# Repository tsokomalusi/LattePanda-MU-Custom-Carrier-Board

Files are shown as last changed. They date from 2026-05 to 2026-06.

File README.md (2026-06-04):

# LattePanda MU Custom Carrier Board

## High Speed PCB Design in KiCad

This repository contains a high-speed PCB design practice project created in KiCad
as part of the High Speed Design with KiCad course by D. Peter Dalmaris.

The primary goal of this project was to gain practical experience with modern
high-speed PCB layout techniques, signal integrity awareness, PCB stackup planning,
and manufacturability considerations.

# Project Background

The project workflow was inspired by the DFRobot LattePanda MU Carrier Board.

As part of the learning process:

- Existing PCB design constraints were studied
- PCB stackup parameters were imported into KiCad
- Routing practices from the reference design were analyzed
- High-speed layout techniques were explored through practical implementation
- Differential pair routing and length tuning techniques were practiced
- Teardrops were implemented throughout the PCB design process

PCIe functionality was not implemented, as the primary focus of the project
was PCB layout practice, signal routing exposure, and understanding high-speed
design workflows.

# 3D PCB Views

## Top Side
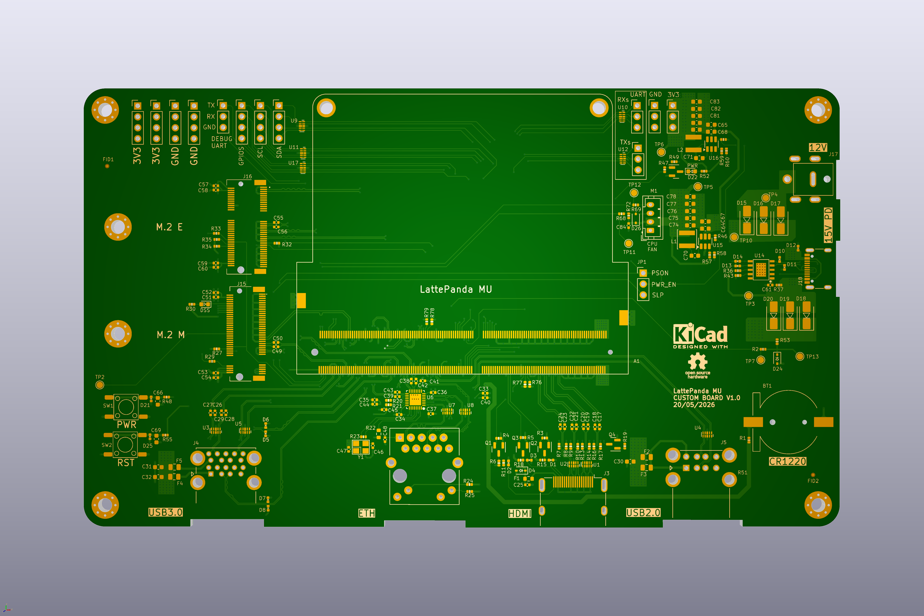
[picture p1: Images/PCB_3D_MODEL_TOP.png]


## Bottom Side
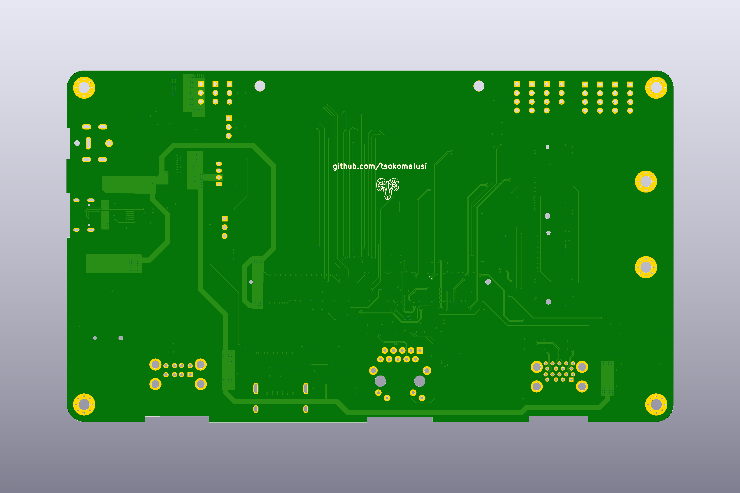
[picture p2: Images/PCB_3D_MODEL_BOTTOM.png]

## Overview

# Technologies & Concepts

 USB 3.0 high-speed routing
- HDMI interface routing
- Gigabit Ethernet routing
- M.2 connector integration
- Differential pair routing and length tuning
- Controlled impedance awareness
- PCB stackup planning
- Return path considerations
- Teardrop implementation
- DFM analysis using NextPCB HQDFM tools

## Design Goals

The project focused on learning and applying:

- High-speed routing practices
- Differential pair management
- Signal integrity fundamentals
- PCB stackup awareness
- Manufacturability considerations

# PCB Stackup & Impedance Planning

The PCB stackup and impedance calculations were reviewed using the NextPCB
impedance calculator and stackup tools.

## Impedance Calculator

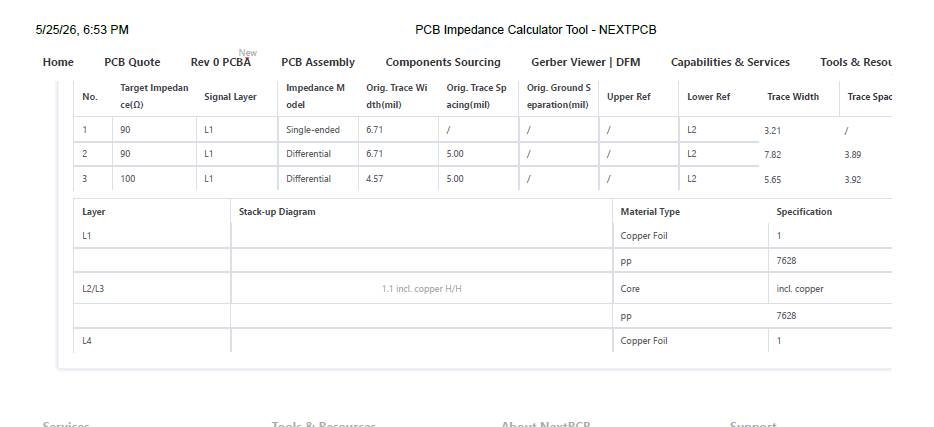
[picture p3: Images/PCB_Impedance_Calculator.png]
IMPEDANCE_CAL


## NextPCB Stackup : Huaqiu04161H03-7628

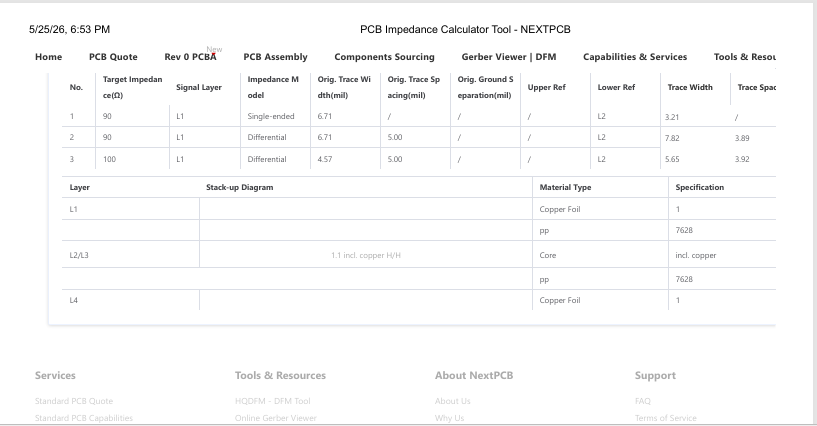
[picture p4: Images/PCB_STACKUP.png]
PCB_STACKUP


## KiCad Stackup Configuration

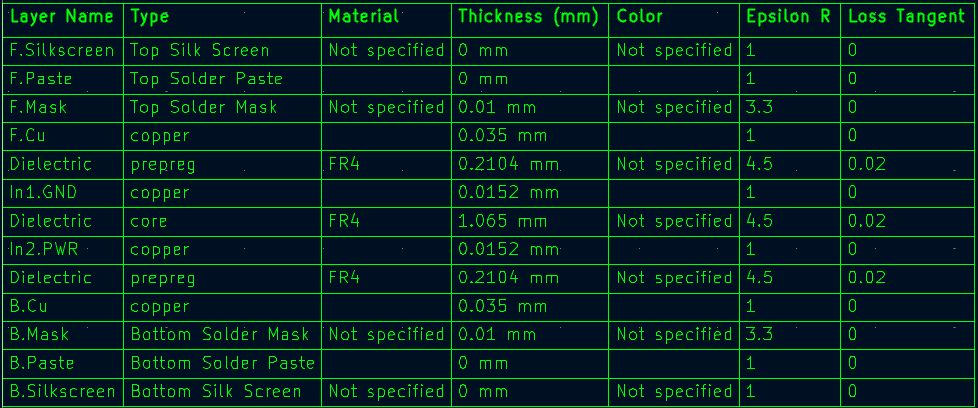
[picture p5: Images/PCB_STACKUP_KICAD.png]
PCB_STACKUP


## PCB Layout

### Full PCB Overview

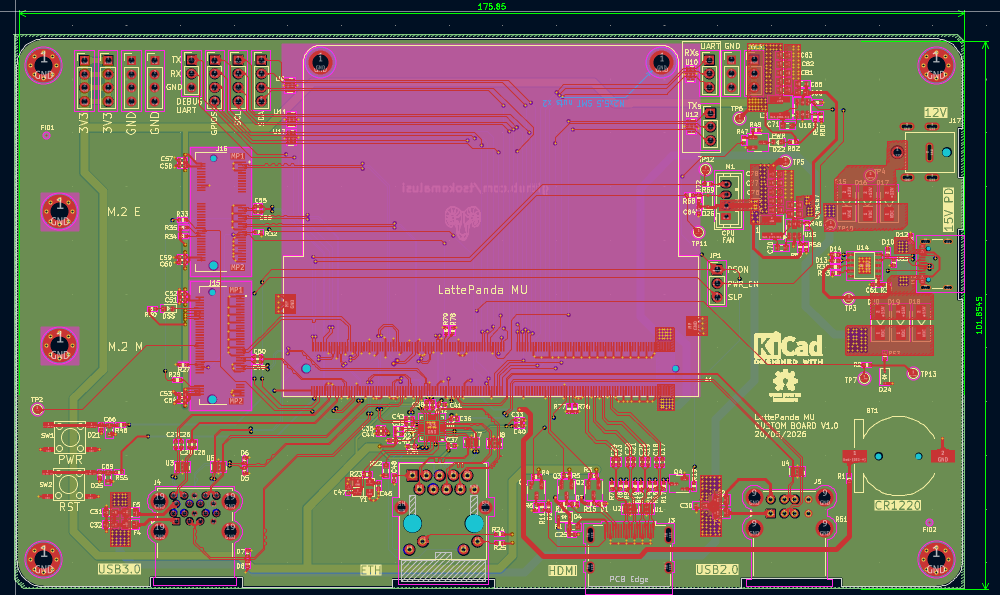
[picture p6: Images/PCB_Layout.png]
PCB Layout


# High-Speed Routing Examples

### USB 3.0 Routing

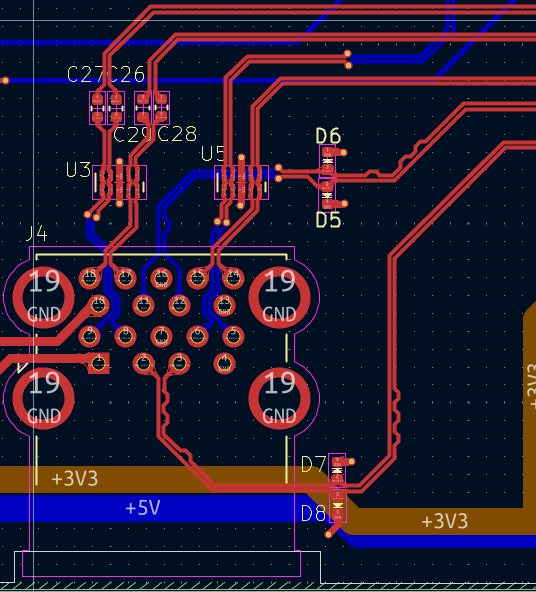
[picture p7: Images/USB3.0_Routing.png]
USB3 Routing


### Notes

- Differential pair routing applied to SuperSpeed signals
- Length tuning performed using KiCad tuning tools
- Pair spacing kept as consistent as possible
- Via transitions minimized where practical
- Teardrops applied throughout the routing process
- ESD protection placed close to connectors

### HDMI Routing

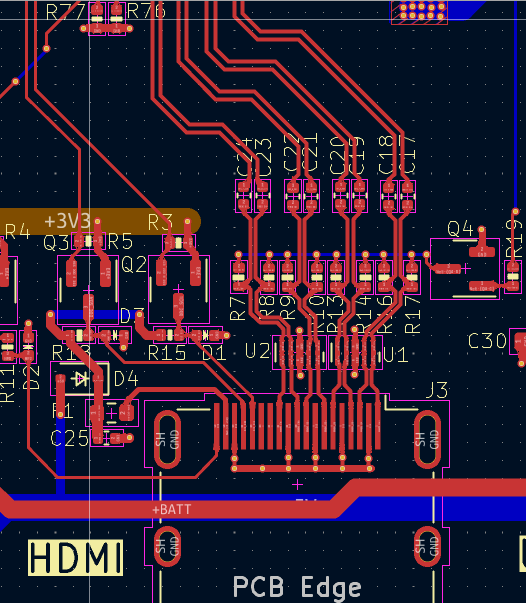
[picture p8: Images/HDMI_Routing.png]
HDMI Routing

### Notes

- TMDS differential pair routing implemented
- Length tuning and routing symmetry considered
- High-speed signal paths prioritized
- Teardrops used to improve routing transitions

### Gigabit Ethernet Routing

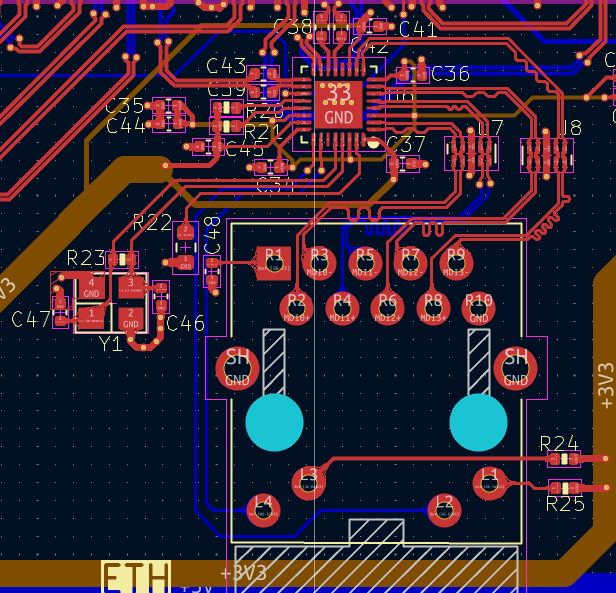
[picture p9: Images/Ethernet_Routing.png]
Ethernet Routing

### Notes

- Differential pair routing used for Ethernet signals
- Return path continuity considered
- Routing isolation considered where possible
- Length matching practices applied where practical

# Schematics
Detailed Schematic of this project can be found within this repository.
[Schematic](https://github.com/tsokomalusi/LattePanda-MU-Custom-Carrier-Board/blob/main/LattePandaMU_Carrier_Custom_Board.pdf)

## DFM Review

The design was analyzed using the NextPCB DFM tool to identify:

- trace width violations
- spacing violations
- drill clearance concerns
- manufacturability issues

This exercise helped reinforce practical PCB manufacturing constraints and layout discipline.

## Lessons Learned

- High-speed routing requires careful planning before layout begins
- PCB stackup directly affects routing constraints and impedance behavior
- Differential pair routing introduces spacing and tuning challenges
- Length tuning requires balancing routing quality and board space
- Reference designs are valuable learning tools for understanding real-world layouts
- DFM analysis helps identify manufacturing issues early in the design process
- Teardrops improve routing robustness and manufacturability
- High-speed PCB design involves both electrical and mechanical tradeoffs

## TOOLCHAIN

- KiCad — schematic capture and PCB layout
- Git & GitHub — version control and project hosting
- NextPCB HQDFM — DFM analysis and manufacturability review
  
## Disclaimer

This project was created for educational and portfolio purposes.

The board has not been fabricated or electrically validated.
PCIe - not implemented to reduce complexity at this stage, but can be future enhancement for V2.0 hopefully.

The DFM analysis is still work in progress.

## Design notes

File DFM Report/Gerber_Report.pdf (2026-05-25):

## HQDFM Design for Manufacture(DFM) Report

File name: Gerber

Time: 2026-05-25Layer count:4 | PCB Thickness: 1.60 | Quantity: 5
mm

Approved items

Urgent Issues

Issue Items 25

2

5

Basic Board Specs | Trace Width/Spacing | 6.00/4.00mil
| Milling Density | 31.4342m/m²
| Surface Finish Area | 12.08%
| Test Point Count | 1068

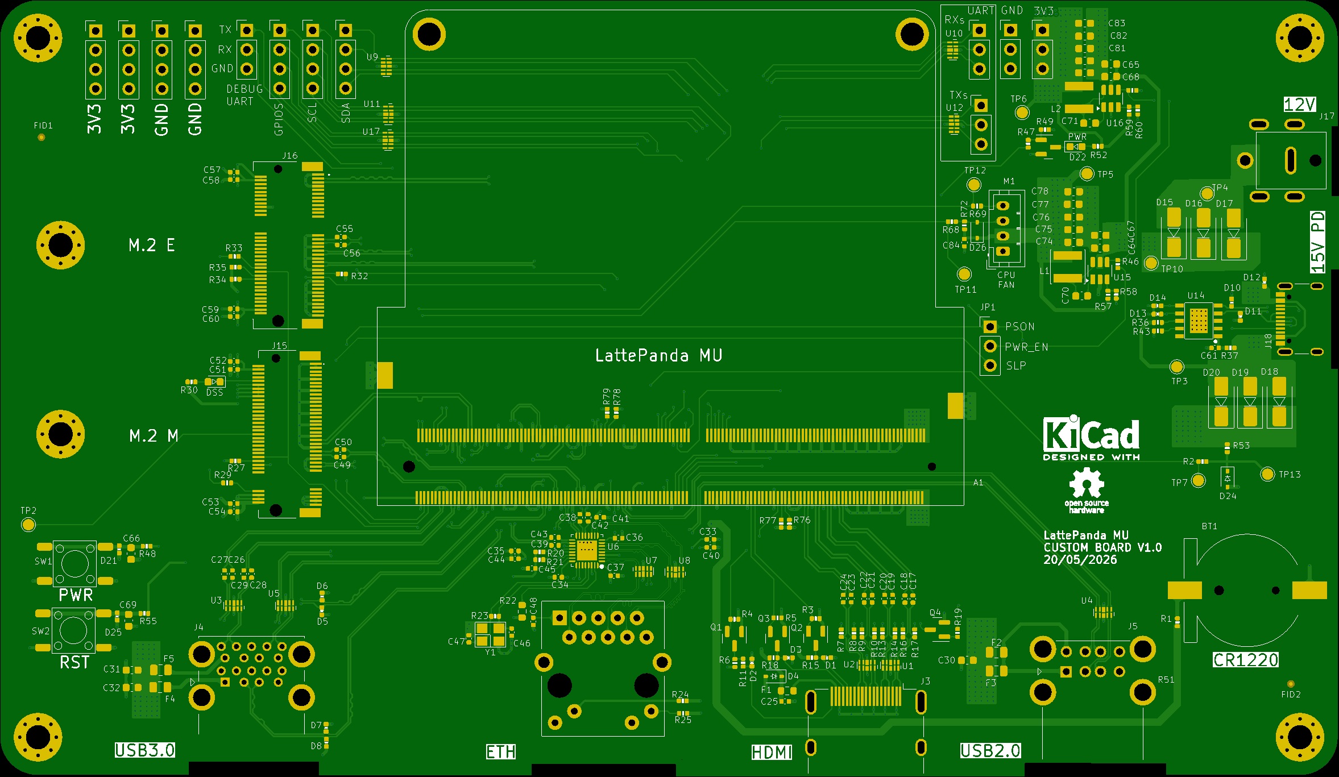
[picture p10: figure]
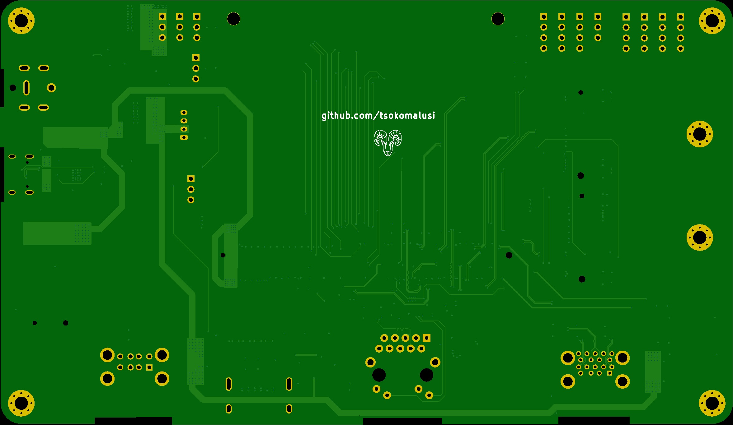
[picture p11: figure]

Type | Category | No. of Checks | Result
| Open/Shorts (IPC) | 1 | Fail
| Signal Integrity | 4 | Pass
| Smallest Trace Width | 1 | Pass 10
| Smallest Trace Spacing | 3 | Pass 581 , Fail 319
| SMD Pad Spacing | 1 | Pass
| Pad Size | 3 | Pass 54
| Hatched Copper Pour | 2 | Pass
| Annular Ring Size | 2 | Pass 3 , Fail 3
| Drill to Copper | 5 | Pass 1473 , Fail 42
| Copper-to-Board Edge | 2 | Pass 3 , Fail 56
| Holes on SMD Pads | 4 | Pass
PCB Drilling Analysis | Drill Diameter | 8 | Pass 61 , Fail 2
| Drill Spacing | 4 | Pass 457 , Fail 2
| Drill to Board Edge | 4 | Pass 2
| Drill Hole Density | 1 | Pass
| Special Drill Holes | 2 | Pass
| Drill Hole Errors | 3 | Pass
PCB Solder Mask Analysis | Solder Mask Dam | 2 | Pass 15
| Missing SMask Opening | 1 | Pass
| Solder Paste Area | 1 | Pass
PCB Silk Analysis | Silkscreen Spacing | 1 | Pass 15

PCB Trace Analysis

PCBA Component Analysis | Component Spacing | 1 | Fail
| Comp.-to-Board-Edge | 3 | Fail
| Component Silkscreen Spacing | 0 | Fail
| Pad Count Mismatch | 4 | Fail
| Designator Length | 0 | Fail
| Double-sided Components | 1 | Pass
| Mid Mount Comp | 1 | Pass
| Comp Height Analysis | 2 | Pass
PCBA Pin Analysis | SMT Pad Analysis | 8 | Fail
| Through-hole Pins | 10 | Fail
PCBA Pad Analysis | Chip Pads | 60 | Fail
PCBA Fiducial Analysis | Fiducial Count | 1 | Fail
| Fiducial Analysis | 4 | Pass

ID | Check | Limits | Value | Issue | Image | Position | Qty | Level

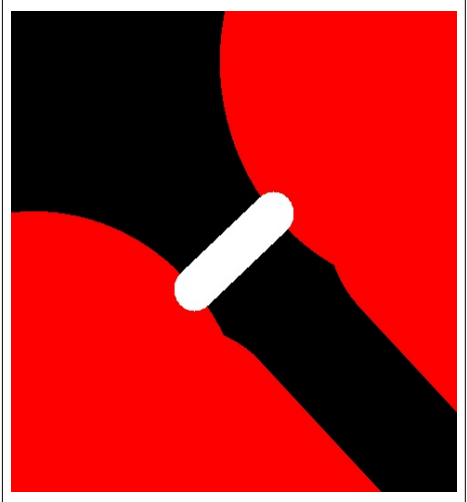
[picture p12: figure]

1

Smallest
Trace

### Spacing_S

### MD Pad

Spacing

4,6,10

3.89

### mil

For most factories, the
minimum pad-to-pad
spacing requirement is
around 3-4 mil. Failure to meet the factory's
requirement could result in incomplete solder mask
dams between the pads,
thereby increasing the risk of incomplete etching of
the pads, which decrease
manufacturing efficiency
and yield, and affect the
reliability of the boards. Pad-to-pad spacings of

3.89mil were detected in
your design. The spacing
should be at least 6 mil
where possible. For solder mask covered pads, 4 mil
spacing is sufficient.
123.71,-97.42 | 7 | Risk

2

Smallest
Trace
Spacing_Tr

ace
Spacing

3.5,4,5

0.10

mm

Trace-to-trace spacing of
3.89mil were detected in
your design. This could
result in incomplete

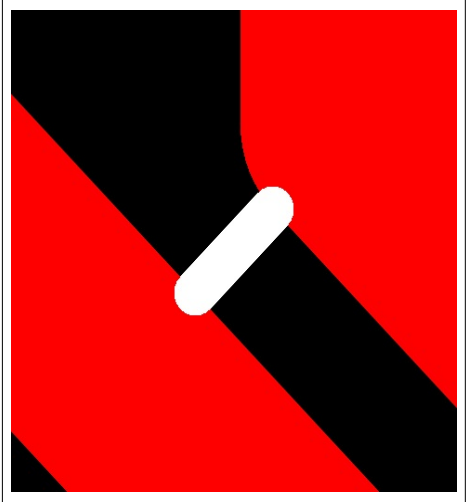
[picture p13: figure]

etching between the traces, thereby producing shorts, which decrease

manufacturing efficiency
and yield, and affect the
reliability of the boards. It is recommended to
increase the spacing to at least 6 mil for regular
routing and at least 4 mil in high density areas, such as when routing fine pitch
BGAs.
112.73,-69.45 | 81 | Risk

3

Annular

### Ring Size_PTH

Annular

### Ring

6,7,8

0.07

mm

### PTH Pad Rings2.93 mil in

size were detected in your design. This could increase the risk of tangency or
breakouts, which decrease
electrical reliability and yield, and affect the
reliability of the boards. It is recommended that PTH
Pad Rings have a width of
at least 6 mil.
118.16,-42.35 | 4 | Risk

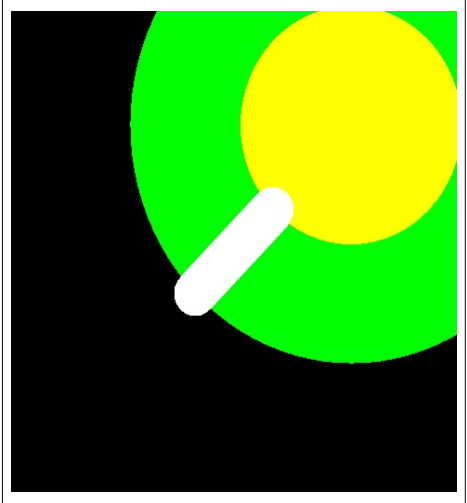
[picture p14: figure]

4

Annular

### Ring

### Size_Via

Annular

### Ring

4,5,6

0.07

mm

Min via annular
rings3.91mil in size were
detected in your design.It will affect production
efficiency and electrical

### reliability. It is

recommended that the
minimum ring size for "via annular rings" be ≥5 mils.
66.61,-122.09 | 2 | Risk

5

### Drill to

Copper_NP
TH-to- Copper

8,10,12

0.15

mm

The NPTH to copper
spacing should be at least

### 8 mil (ideally 12 mil). Spacing less than this could

increase the risk of defects such as exposed copper, which decrease

manufacturing efficiency
and yield, and affect the
reliability of the boards. The NPTH to copper

spacing in your design is
only 5.90mil. It is
recommended to increase
the spacing to at least 12 mil.
98.95,-59.43 | 36 | Risk

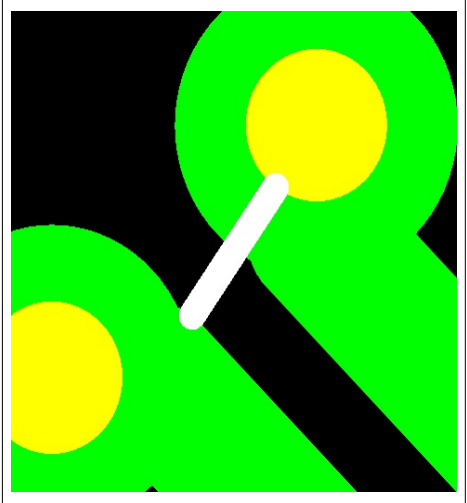
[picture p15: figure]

6

### Drill to

Copper_Vi
a-to-Trace
[Outer]

8,10,12

0.15

mm

Via-to-trace spacing (outer layer) of 8.07mil was
detected in your design. This could increase the risk

of defects such as short
circuits, which decrease
manufacturing efficiency
and yield, and affect the
reliability of the boards. It is recommended to
increase the spacing to at
least 10 mil.
123.78,-97.42 | 431 | Risk

7

C
o

p

p

er-to- Board Edge_Cop per-to- Board Edge

8,11,15

0.2

0

m

# m For m ost factories, th

e copper-to-board edge clearance requirement is 0.2 mm. Failure to meet th

e factory's requirements could increase the risk of exposed copper on the edge of the boards or damaged traces/pads, which decrease manufacturing efficiency and yield, and affect the reliability of the boards. Copper-to-board edge spacing of 7.89mil was detected in your design. It is recommended to increase the spacing to at least 0.25 mm for edge routing and 0.4 mm for v- cuts (v-cut spacing may depends on board thickness). | 10

4.8

3,-13
6.9

6

2

8

### Risk

8

Drill Diameter_
S lot Aspect Ratio | 1.5,2,2

0.2

0

m

m

### Slots with

asp

ect ratio

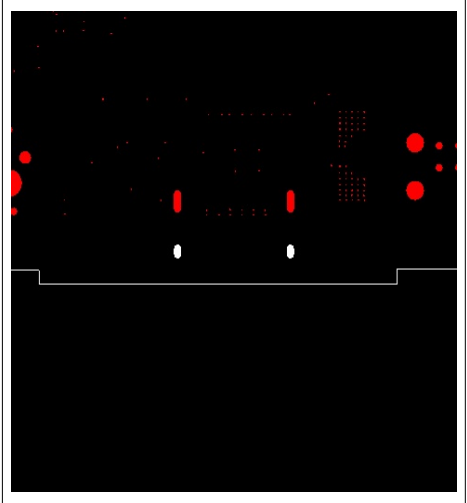
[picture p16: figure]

of 1.89 were detected in your design. This could increase the risk of incomplete drilling of the slot, which decrease manufacturing efficiency and yield, and affect the reliability of the boards. The ratio should be increased to at least 2:1 | 17

6.7

2,-13
5.0

9

6

W

arnin g

9

Drill Diameter_
S

m

### allest Drill Size

0. 19,0.2
5,0. 3

0.2

0

m

m

### Min.Drill:0.2

0
m

m in

### dia

m

eter w
ere

d
etecte

### d in

y

o

ur d
esig
n. S
m
aller drill bits necessitate more frequent replacements, increasing the likelihood of missed holes, misalignment, and rough hole walls. This diminishes manufacturing efficiency, reduces yield, and impacts board reliability. Holes with diameters of 0.1mm or less require laser drilling and must adhere to stringent board width requirements. It is advisable to increase the diameter to at least 0.2mm or 0.3mm to avoid additional costs | 15

0.8

9,-8

7.0

7 13

W

arnin g 10 | Drill Spacing_Di fferent Net Via Spacing | 0.2,0.3,0.4 | 0.24 mm | Different net via spacing of 11.79mil were detected in your design. This could increase the risk of short circuits caused by Conductive Anodic Filament (CAF) electrochemical migration over the lifetime of the PCBs, which decrease manufacturing efficiency and yield, and affect the reliability of the boards. It is recommended to increase the spacing to at least 12 mil. | 123.71,-97.42 | 57 | Warnin g

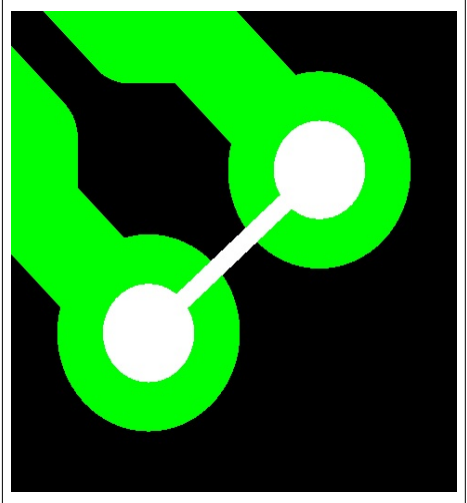
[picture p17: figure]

### 11 Drill Spacing

_

S
a
m

e

N

et Via
S
p

acin
g
0. 19,0.2
5,0. 3

0.2
4

m

m | 13
8.0

0,-9
5.5

9
4

0

2

W

arnin g

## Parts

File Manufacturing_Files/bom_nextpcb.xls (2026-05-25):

Designator* | Quantity* | Manufacturer Part Number* | Manufacturer | Package/Footprint | Description | Procurement Type | Customer Note
Required | Required | Required |  |  |  | Optional 1）Do not populate/install: DNP 2）Customer supplied part: C Learn more >
A1 | 1 | LattePanda_Mu |  | Module_LattePanda:LattePanda_Module_H8.0mm_Horizontal
BT1 | 1 | Battery_Cell |  | A_HDJ_Library:Battery_Holder_CR1220_S8411-45R
C1,C2,C3,C4,C5,C6,C7,C8 | 8 | 220n/50V |  | A_HDJ_Library:C_0402_1005Metric |  | DNP
C9,C10,C13,C15,C85 | 5 | 100n/50V |  | A_HDJ_Library:C_0402_1005Metric |  | DNP
C11 | 1 | 100u/25V |  | A_HDJ_Library:CP_Elec_6.3x7.7 |  | DNP
C12 | 1 | 560u/25V |  | A_HDJ_Library:CP_Elec_6.3x7.7 |  | DNP
C14 | 1 | 10u/10V |  | A_HDJ_Library:C_0402_1005Metric
C17,C18,C19,C20,C21,C22,C23,C24,C25,C26,C27,C28,C29,C52,C53,C54,C58,C59,C60 | 19 | 100nF/50V |  | A_HDJ_Library:C_0402_1005Metric
C30,C31,C32,C64,C65,C67,C68,C74,C75,C77,C78,C79,C80,C82,C83 | 15 | 22u/10V |  | A_HDJ_Library:C_0603_1608Metric
C33,C34,C35,C36,C37,C38,C39,C40,C41,C42,C43,C45,C48,C84 | 14 | 100n/50V |  | A_HDJ_Library:C_0402_1005Metric
C44 | 1 | 10u/50V |  | A_HDJ_Library:C_0402_1005Metric
C46,C47 | 2 | 12p/50V |  | A_HDJ_Library:C_0402_1005Metric
C49,C50,C55,C56 | 4 | 220nF/50V |  | A_HDJ_Library:C_0402_1005Metric
C51,C57 | 2 | 10uF/50V |  | A_HDJ_Library:C_0402_1005Metric
C61 | 1 | 1u/16V |  | A_HDJ_Library:C_0402_1005Metric
C62,C63 | 2 | 1u/16V |  | A_HDJ_Library:C_0402_1005Metric |  | DNP
C66,C69 | 2 | 1u/16V |  | A_HDJ_Library:C_0603_1608Metric
C70,C71 | 2 | 100n/50V |  | A_HDJ_Library:C_0603_1608Metric
C72,C73 | 2 | 12p/50V |  | A_HDJ_Library:C_0402_1005Metric |  | DNP
C76,C81 | 2 | 100n/10V |  | A_HDJ_Library:C_0603_1608Metric
D1,D2,D3,D5,D6,D7,D8 | 7 | ESD5V0B03 |  | A_HDJ_Library:D_0402_1005Metric
D4 | 1 | 1N5819WS |  | A_HDJ_Library:D_SOD-323
D9 | 1 | GREEN |  | A_HDJ_Library:LED_0603_1608Metric
D10,D11,D21,D25 | 4 | ESD9B5.0ST5G |  | A_HDJ_Library:D_0402_1005Metric
D12,D13,D14 | 3 | D_Zener |  | A_HDJ_Library:D_0402_1005Metric |  |  | Replace with DFN1006, although close to 0402
D15,D16,D17,D18,D19,D20 | 6 | D_Schottky |  | A_HDJ_Library:D_SMA
D22 | 1 | LED |  | A_HDJ_Library:LED_0603_1608Metric
D23 | 1 | LED |  | A_HDJ_Library:LED_0603_1608Metric |  | DNP
D24 | 1 | 3V3 Izt=5mA |  | A_HDJ_Library:D_SOD-323
D26 | 1 | 1N5819 |  | Diode_SMD:D_SOD-323
D27 | 1 | 1N5819 |  | Diode_SMD:D_SOD-323 |  | DNP
F1 | 1 | 6V/50mA |  | A_HDJ_Library:R_0603_1608Metric
F2,F3,F4,F5 | 4 | 6V/1A |  | A_HDJ_Library:Fuse_0805_2012Metric
H1,H2,H3,H4,H7,H8 | 6 | MountingHole_Pad |  | A_HDJ_Library:MountingHole_3.2mm_M3_Pad_Via |  |  | Delete- Not part of assembly
H5,H6 | 2 | MountingHole_Pad |  | A_HDJ_Library:MountingHole_3mm_M2_Pad_TopOnly |  |  | Delete- Not part of assembly
J1,J8,J10,J11,J14 | 5 | Conn_01x03_Pin |  | A_HDJ_Library:PinHeader_1x03_P2.54mm_Vertical
J2 | 1 | Bus_PCI_Express_x4 |  | A_HDJ_Library:PCIe_x4_Gen3Slot_Connectors |  | DNP
J3 | 1 | HDMI_A |  | A_HDJ_Library:HDMI_A_Molex_208658-1001_Horizontal
J4 | 1 | USB3_A_Stacked |  | A_HDJ_Library:USB3_A_Molex_48406-0001_Horizontal_Stacked
J5 | 1 | USB_A_Stacked |  | A_HDJ_Library:USB_A_CUI_UJ2-ADH-TH_Horizontal_Stacked
J6 | 1 | RJ45_RB1-125B8G1A |  | A_HDJ_Library:RJ45_UDE_RB1-125B8G1A
J7,J9,J12,J13,J19,J20,J21 | 7 | Conn_01x04_Pin |  | A_HDJ_Library:PinHeader_1x04_P2.54mm_Vertical
J15 | 1 | Bus_M.2_Socket_M |  | A_HDJ_Library:PCIe_M.2_Connectors_P=0.5mm_H=4.2mm_KeyM
J16 | 1 | Bus_M.2_Socket_E |  | A_HDJ_Library:PCIe_M.2_Connectors_P=0.5mm_H=4.2mm_KeyE
J17 | 1 | Barrel_Jack_Switch |  | A_HDJ_Library:DC_Jack_DC007B_30V_10A
J18 | 1 | USB_C_Receptacle_USB2.0_16P |  | A_HDJ_Library:USB_C_Receptacle_G-Switch_GT-USB-7010ASV
JP1 | 1 | Jumper_3_Bridged12 |  | A_HDJ_Library:PinHeader_1x03_P2.54mm_Vertical |  | DNP
JP2 | 1 | NTC-Test |  | Jumper:SolderJumper-2_P1.3mm_Open_RoundedPad1.0x1.5mm
L1,L2 | 2 | 2u2/4.3A |  | A_HDJ_Library:L_Sunlord_SWPA4020S
M1 | 1 | Fan_4pin |  | A_HDJ_Library:JST_PH_B4B-PH-K_1x04_P2.00mm_Vertical
M2 | 1 | Fan_4pin |  | A_HDJ_Library:JST_PH_B4B-PH-K_1x04_P2.00mm_Vertical |  | DNP
Q1,Q2,Q3,Q4 | 4 | 2SK3018 |  | A_HDJ_Library:SOT-23
Q5,Q6 | 2 | 2N7002 |  | A_HDJ_Library:SOT-23 |  | DNP
Q7 | 1 | AON7262E |  | A_HDJ_Library:MOSFET_PDFN8_3.3x3.3 |  | DNP
Q8 | 1 | 2N7002 |  | A_HDJ_Library:SOT-23
R1,R11,R37,R47 | 4 | 1K/1% |  | A_HDJ_Library:R_0402_1005Metric
R2,R20,R21,R34,R35,R36,R49,R58,R78,R79 | 10 | 10K/1% |  | A_HDJ_Library:R_0402_1005Metric
R3,R5,R15,R18,R30 | 5 | 2.2K/1% |  | A_HDJ_Library:R_0402_1005Metric
R4,R23 | 2 | 1M/1% |  | A_HDJ_Library:R_0402_1005Metric
R6 | 1 | 21.5K/1% |  | A_HDJ_Library:R_0402_1005Metric
R7,R8,R9,R10,R13,R14,R16,R17,R24,R25 | 10 | 470R/1% |  | A_HDJ_Library:R_0402_1005Metric
R19,R52,R53 | 3 | 2K2/1% |  | A_HDJ_Library:R_0402_1005Metric
R22 | 1 | 2K49/1% |  | A_HDJ_Library:R_0603_1608Metric
R27,R29,R32,R33 | 4 | 0R/1% |  | A_HDJ_Library:R_0402_1005Metric
R28,R73,R75 | 3 | 0R/1% |  | A_HDJ_Library:R_0402_1005Metric |  | DNP
R38,R40,R50,R56,R63 | 5 | 10K/1% |  | A_HDJ_Library:R_0402_1005Metric |  | DNP
R39 | 1 | 2K2/1% |  | A_HDJ_Library:R_0402_1005Metric |  | DNP
R41,R42,R54,R66,R67,R70 | 6 | 21K5/1% |  | A_HDJ_Library:R_0402_1005Metric |  | DNP
R43 | 1 | 56K/1% |  | A_HDJ_Library:R_0402_1005Metric
R44,R45 | 2 | 100K/1% |  | A_HDJ_Library:R_0402_1005Metric |  | DNP
R46,R48,R55,R69 | 4 | 100R/1% |  | A_HDJ_Library:R_0402_1005Metric
R51,R76,R77 | 3 | 100K/1% |  | A_HDJ_Library:R_0402_1005Metric
R57 | 1 | 75K/1% |  | A_HDJ_Library:R_0402_1005Metric
R59 | 1 | 21K5K/1% |  | A_HDJ_Library:R_0402_1005Metric
R60,R72 | 2 | 4K7/1% |  | A_HDJ_Library:R_0402_1005Metric
R64,R65,R74 | 3 | 4K7/1% |  | A_HDJ_Library:R_0402_1005Metric |  | DNP
R68 | 1 | 21K5/1% |  | A_HDJ_Library:R_0402_1005Metric
R71 | 1 | 100R/1% |  | A_HDJ_Library:R_0402_1005Metric |  | DNP
SW1,SW2 | 2 | SW_Push |  | A_HDJ_Library:SW_Push_6x6x6
TH1 | 1 | NTC_10K |  | A_HDJ_Library:R_0603_1608Metric |  | DNP
TP1,TP8,TP9 | 3 | TestPoint |  | A_HDJ_Library:TestPoint_Pad_D1.5mm |  | DNP
TP2,TP3,TP4,TP5,TP6,TP7,TP10,TP11,TP12,TP13 | 10 | TestPoint |  | A_HDJ_Library:TestPoint_Pad_D1.5mm
U1,U2,U3,U4,U5,U9,U10,U11,U12,U17 | 10 | ULC0524P |  | A_HDJ_Library:Diodes_UDFN-10_1.0x2.5mm_P0.5mm
U6 | 1 | RTL8111H-CG-RH |  | A_HDJ_Library:QFN-32-1EP_4x4mm_P0.4mm_EP2.65x2.65mm
U7,U8 | 2 | ULC0524P |  | A_HDJ_Library:Diodes_UDFN-10_1.0x2.5mm_P0.5mm |  | DNP
U13 | 1 | TL431DBZ |  | A_HDJ_Library:SOT-23 |  | DNP
U14 | 1 | USB PDç‰å¿«å……å è®®å —ç”µèŠ¯ç‰‡-CH224K-ESSOP10 |  | A_HDJ_Library:ESSOP-10-1EP_3.9x5mm_P1.0mm_EP3.2x2.3
U15,U16 | 2 | LM2734X |  | Package_TO_SOT_SMD:TSOT-23-6
Y1 | 1 | 25 MHz |  | A_HDJ_Library:Crystal_SMD_3225-4Pin_3.2x2.5mm
FID1,FID2 | 2 | Fiducial |  | A_HDJ_Library:Fiducial_0.5mm_Mask1mm |  |  | Delete - Not part of assembly

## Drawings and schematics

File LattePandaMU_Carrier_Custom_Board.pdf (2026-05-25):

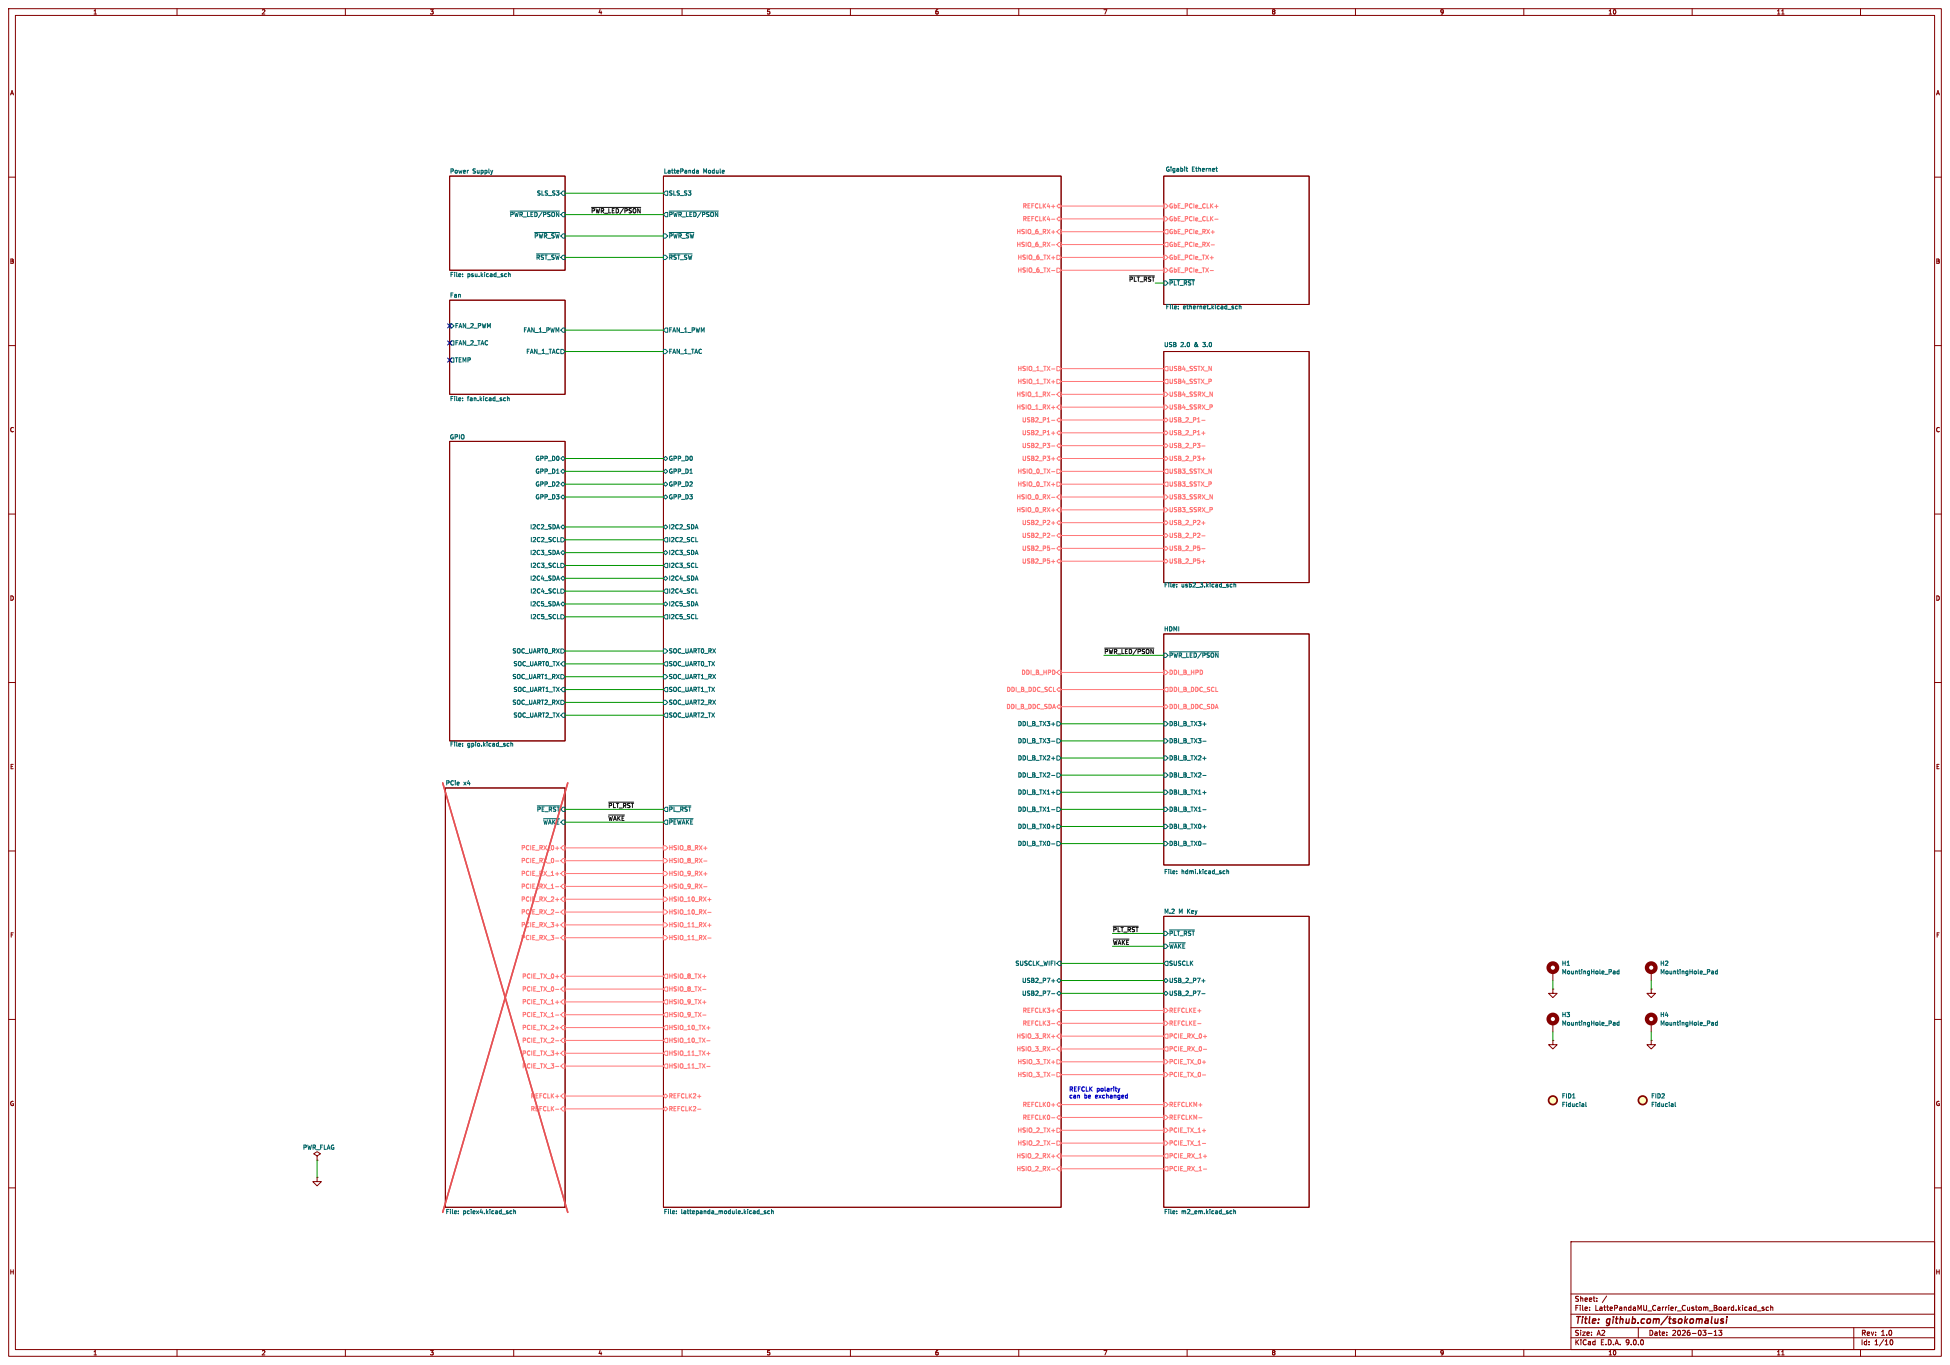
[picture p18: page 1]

Gigabit Ethernet File: ethernet.kicad_sch USB3_SSRX_N

~{PWR_LED/PSON} HDMI File: hdmi.kicad_sch

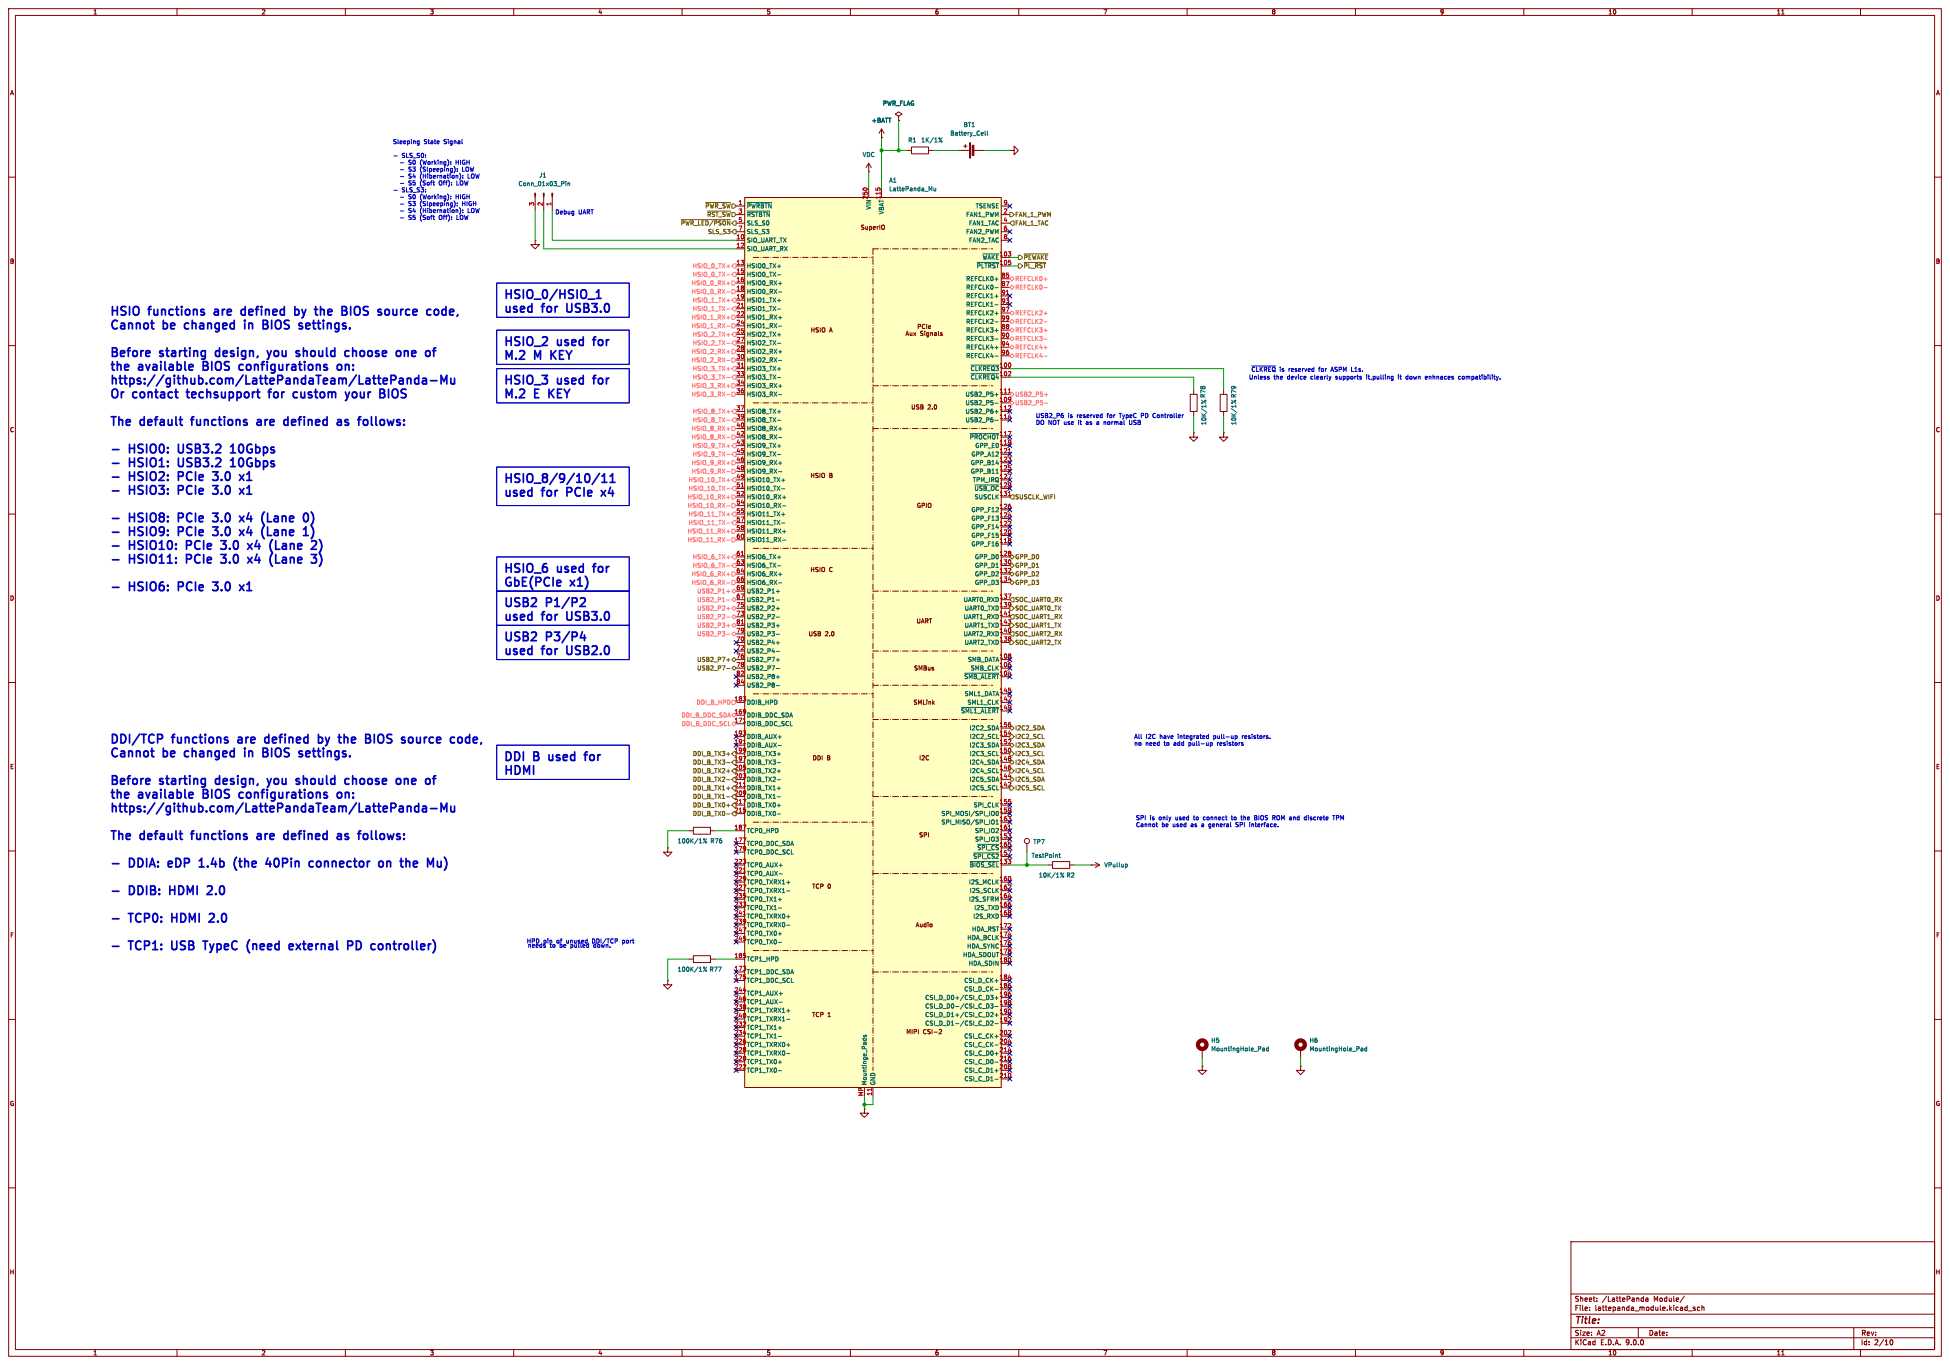
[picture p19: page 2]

USB2_P6 is reserved for TypeC PD Controller DO NOT use it as a normal USB HSIO functions are defined by the BIOS source code,
Cannot be changed in BIOS settings.

Aux Signals USB 2.0 GPIO

Before starting design, you should choose one of
https://github.com/LattePandaTeam/LattePanda-Mu
Or contact techsupport for custom your BIOS

The default functions are defined as follows: - HSIO0: USB3.2 10Gbps - HSIO1: USB3.2 10Gbps - HSIO2: PCIe 3.0 x1 - HSIO3: PCIe 3.0 x1 - HSIO8: PCIe 3.0 x4 (Lane 0) - HSIO9: PCIe 3.0 x4 (Lane 1) - HSIO10: PCIe 3.0 x4 (Lane 2) - HSIO11: PCIe 3.0 x4 (Lane 3) - HSIO6: PCIe 3.0 x1

HPD pin of unused DDI/TCP port DDI/TCP functions are defined by the BIOS source code,

Cannot be used as a general SPI interface.

The default functions are defined as follows: - DDIA: eDP 1.4b (the 40Pin connector on the Mu) - DDIB: HDMI 2.0 - TCP0: HDMI 2.0 - TCP1: USB TypeC (need external PD controller)

needs to be pulled down.

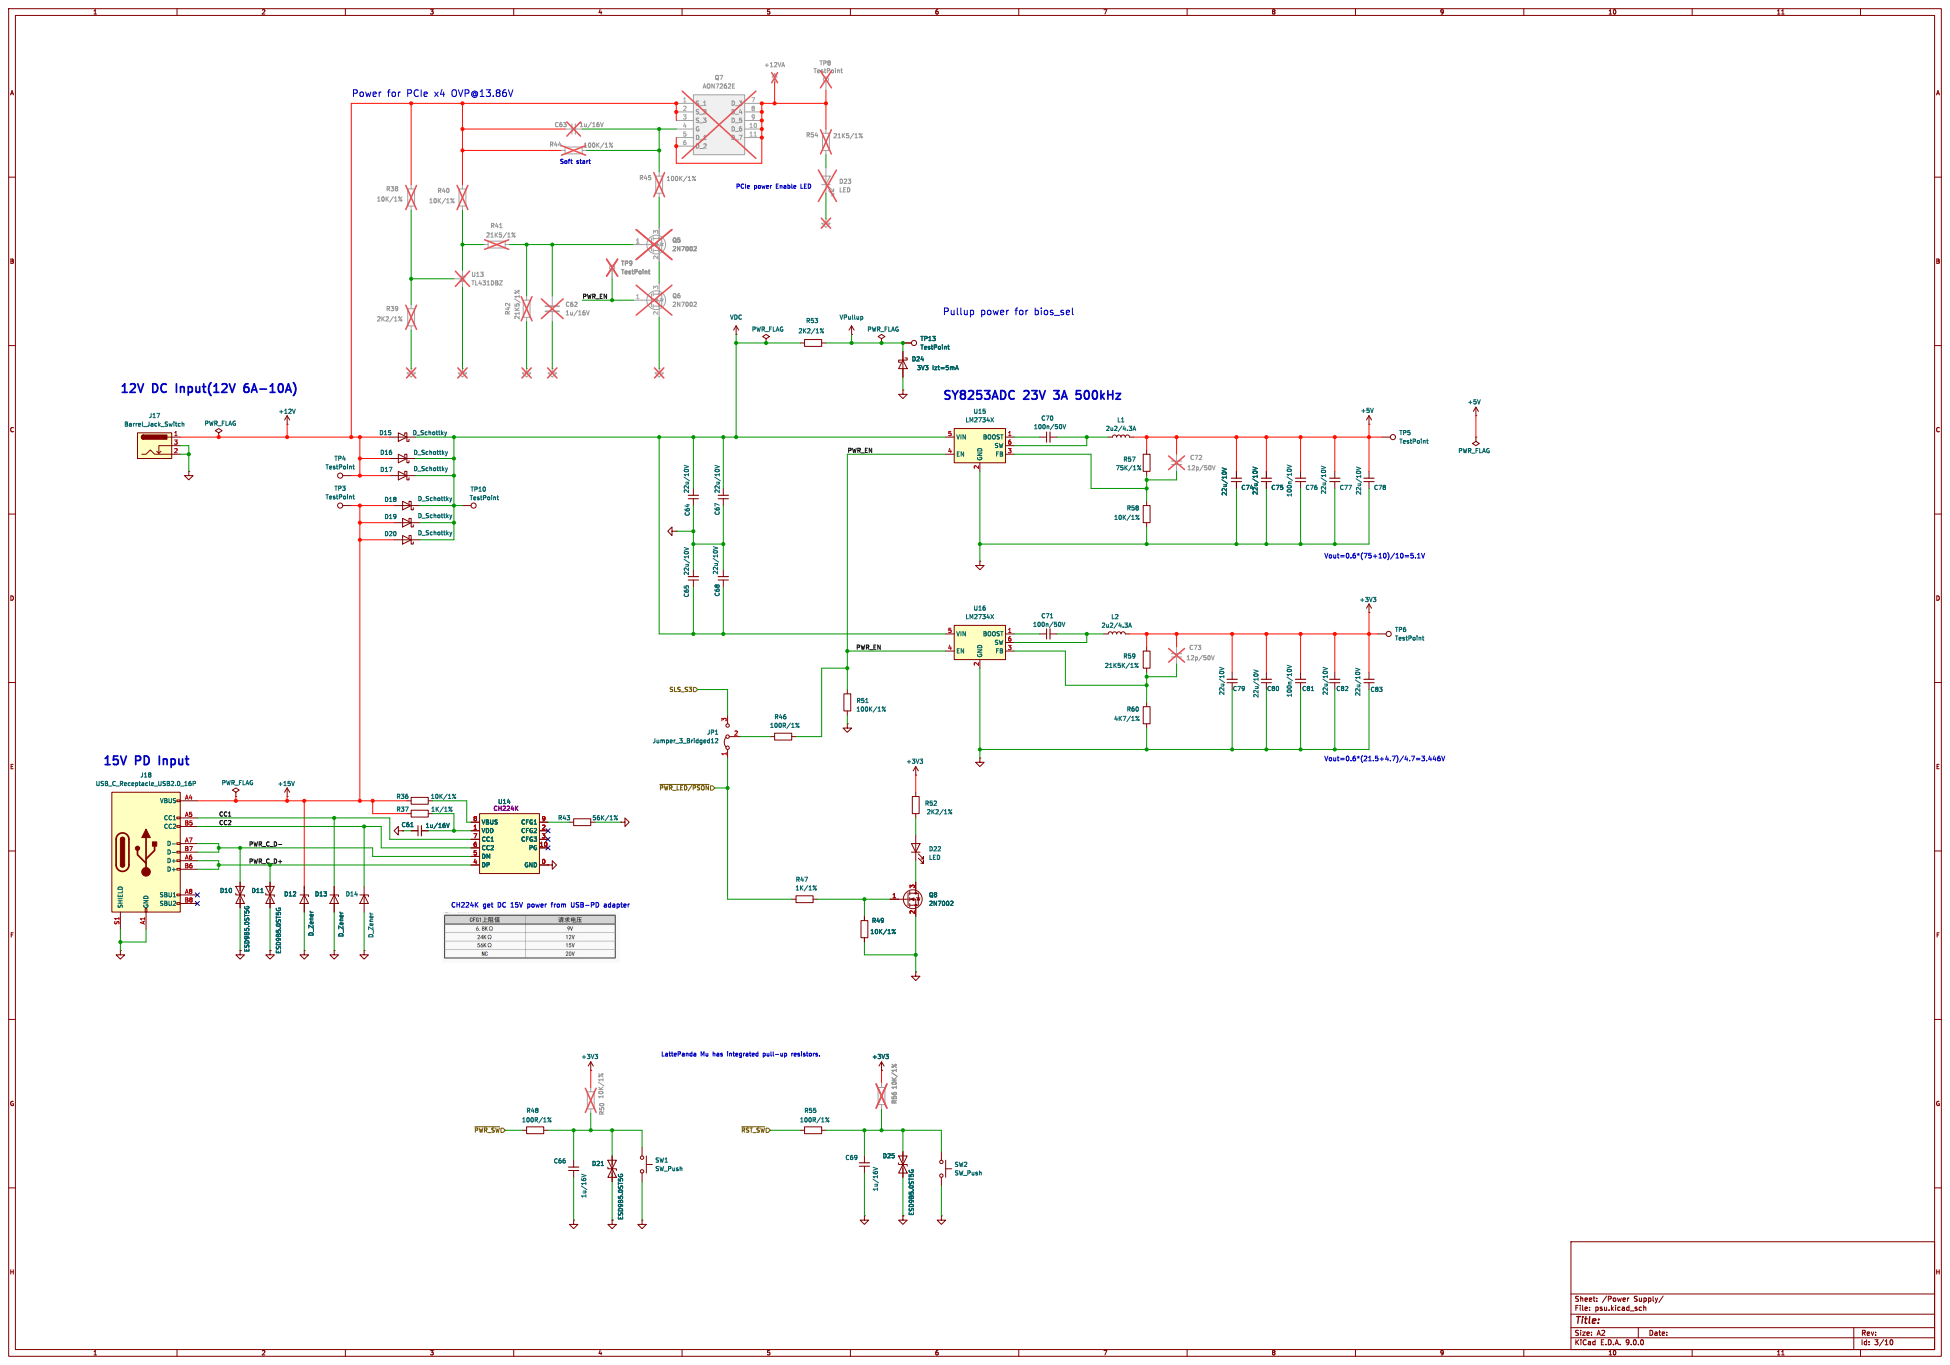
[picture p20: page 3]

PCIe power Enable LED Power for PCIe x4 OVP@13.86V

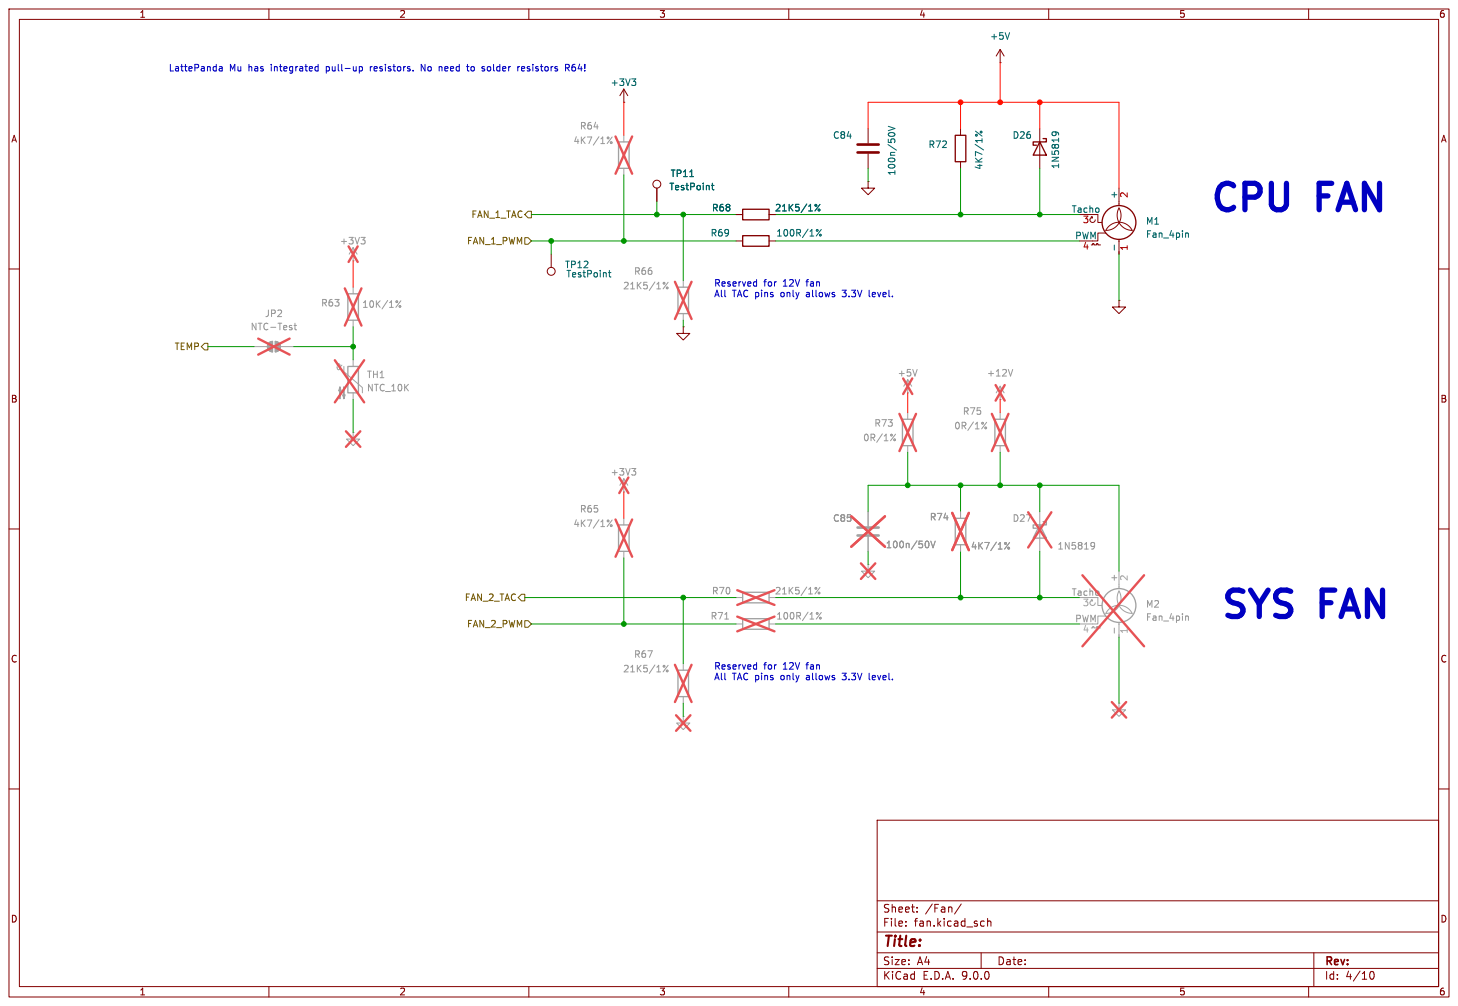
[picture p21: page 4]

Id: 4/10 Title: File: fan.kicad_sch Sheet: /Fan/

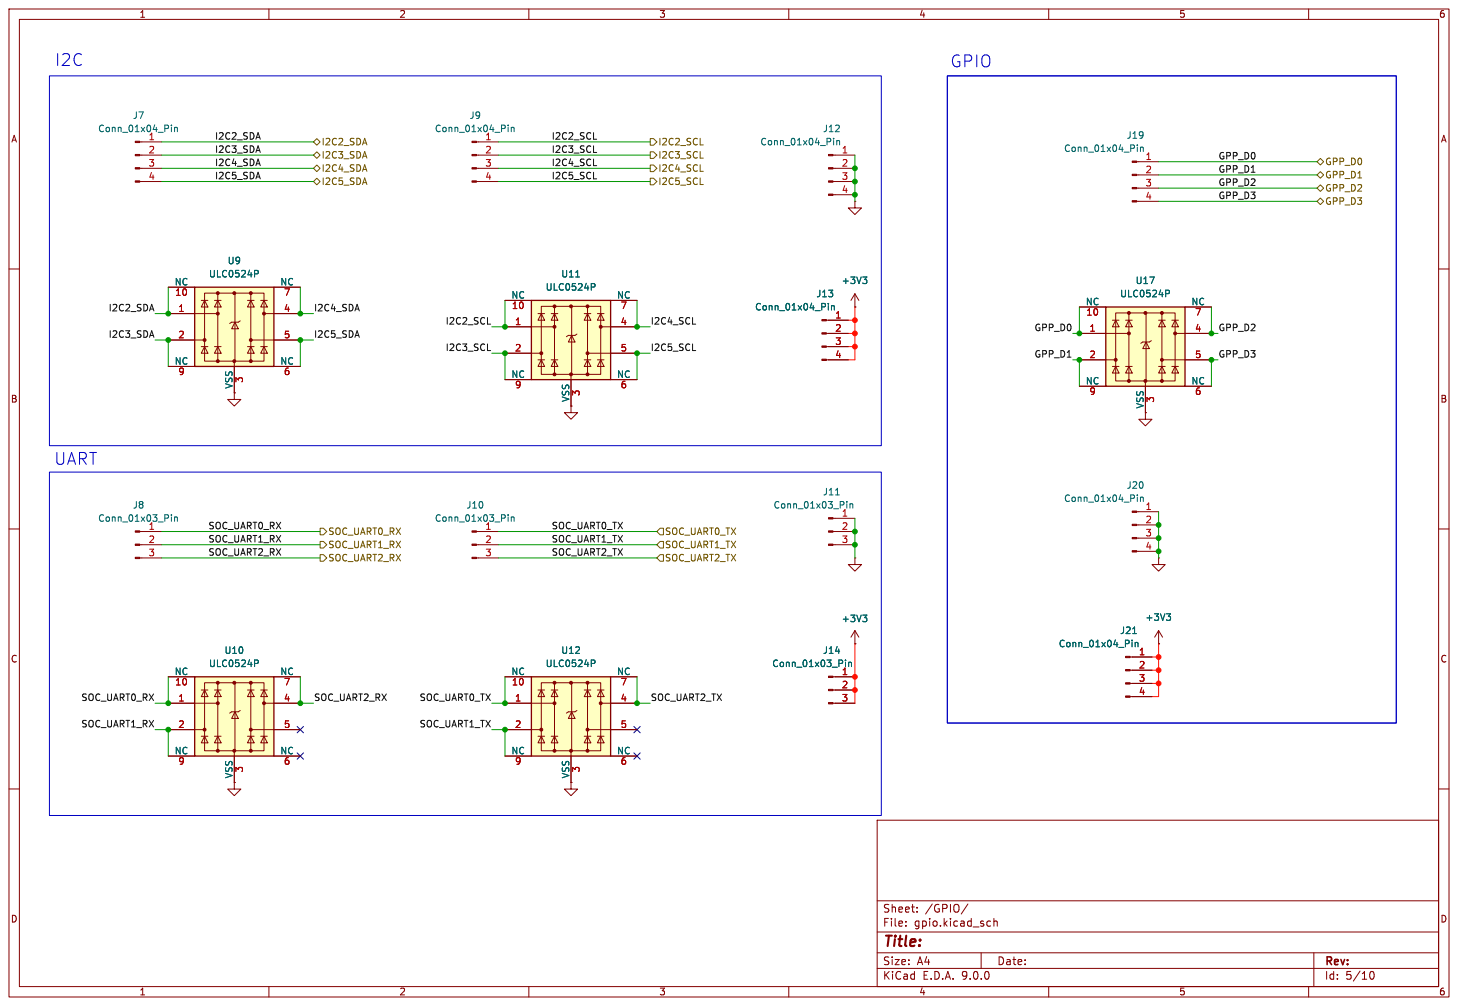
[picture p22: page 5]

Id: 5/10 Title: File: gpio.kicad_sch Sheet: /GPIO/

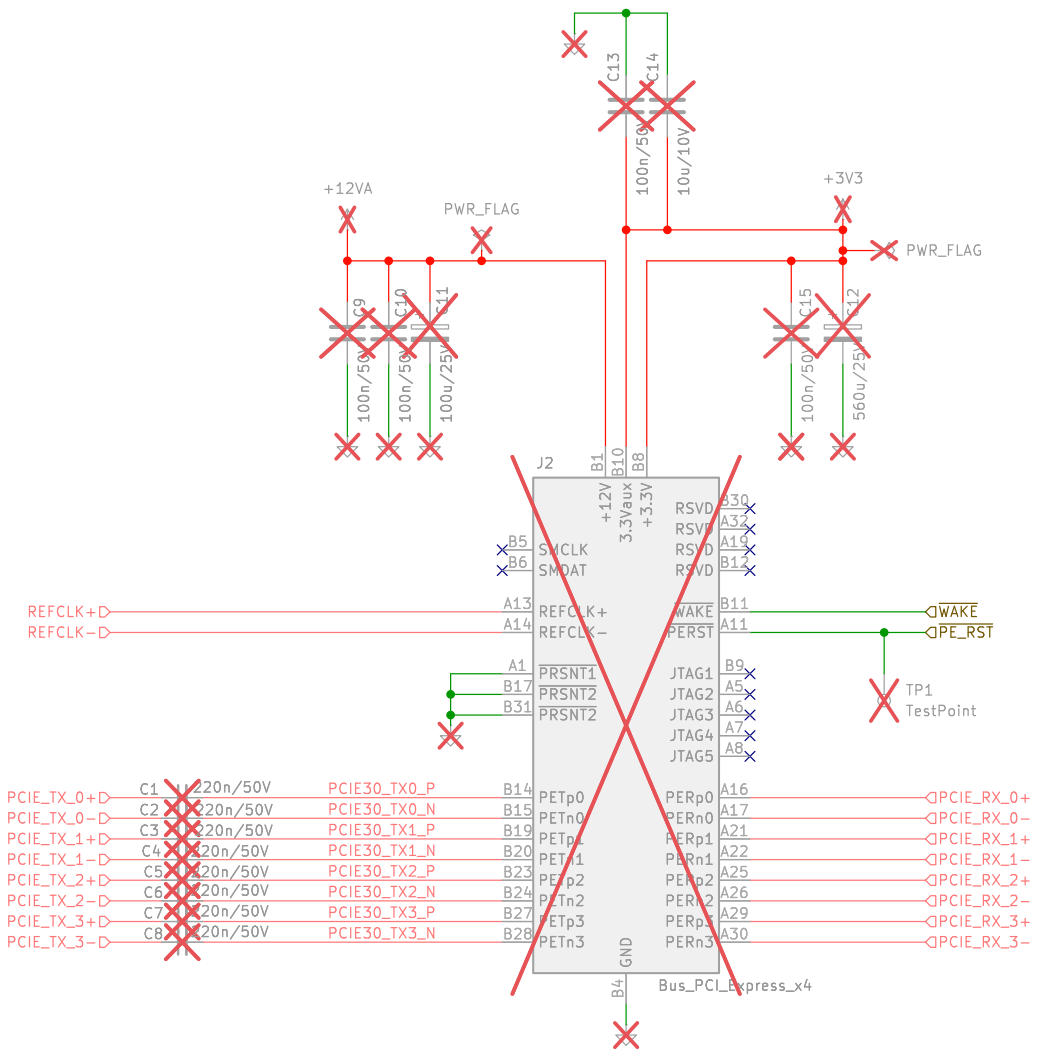
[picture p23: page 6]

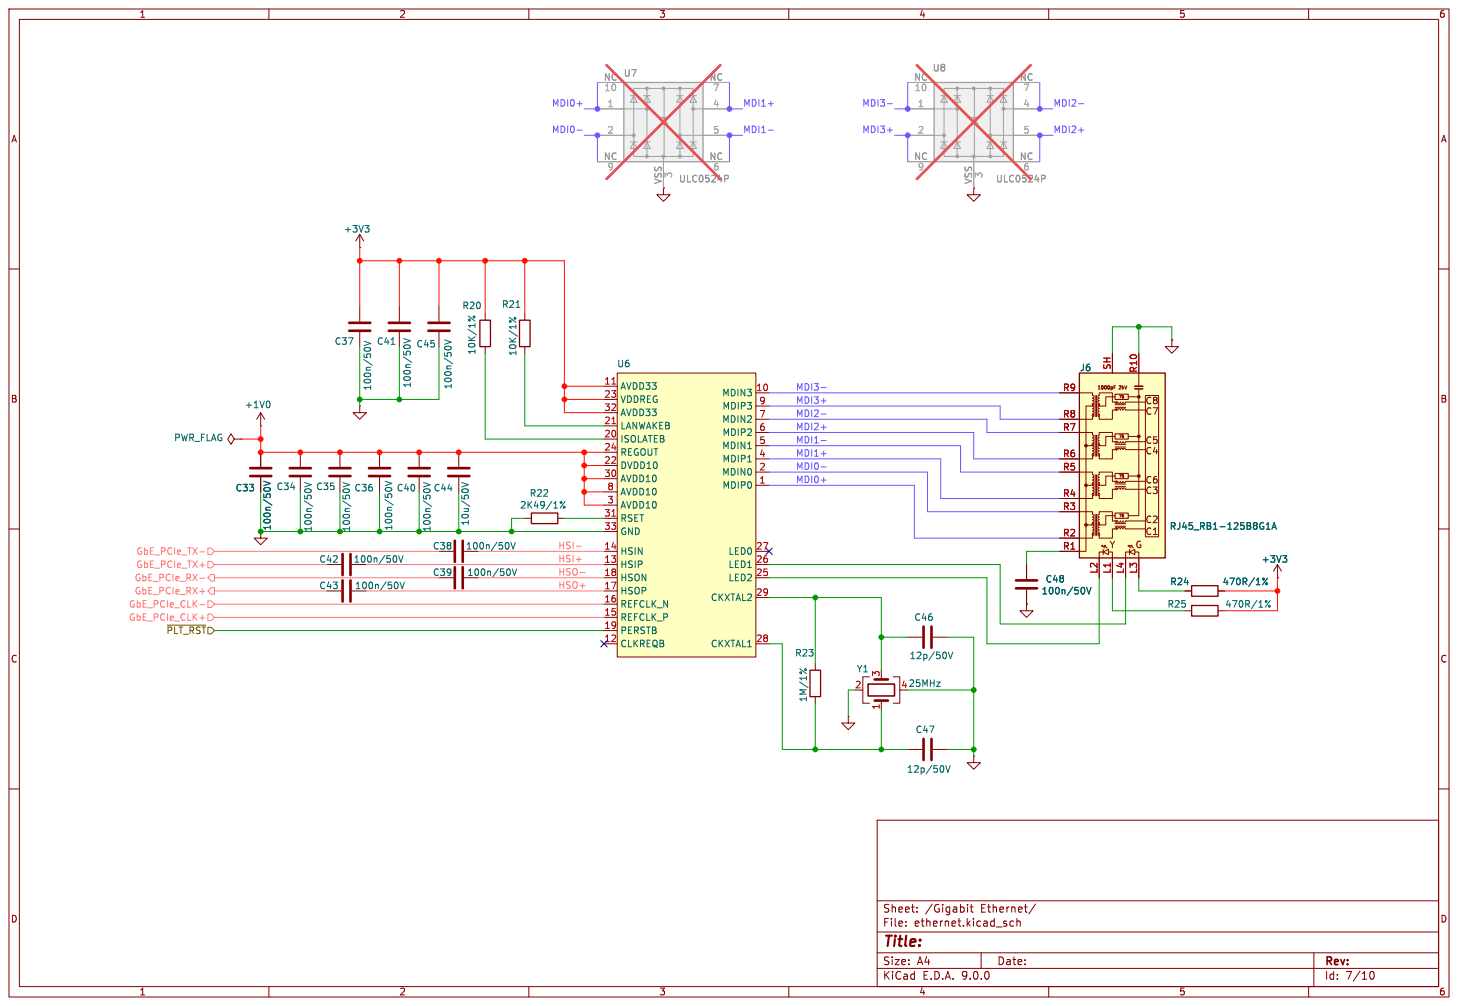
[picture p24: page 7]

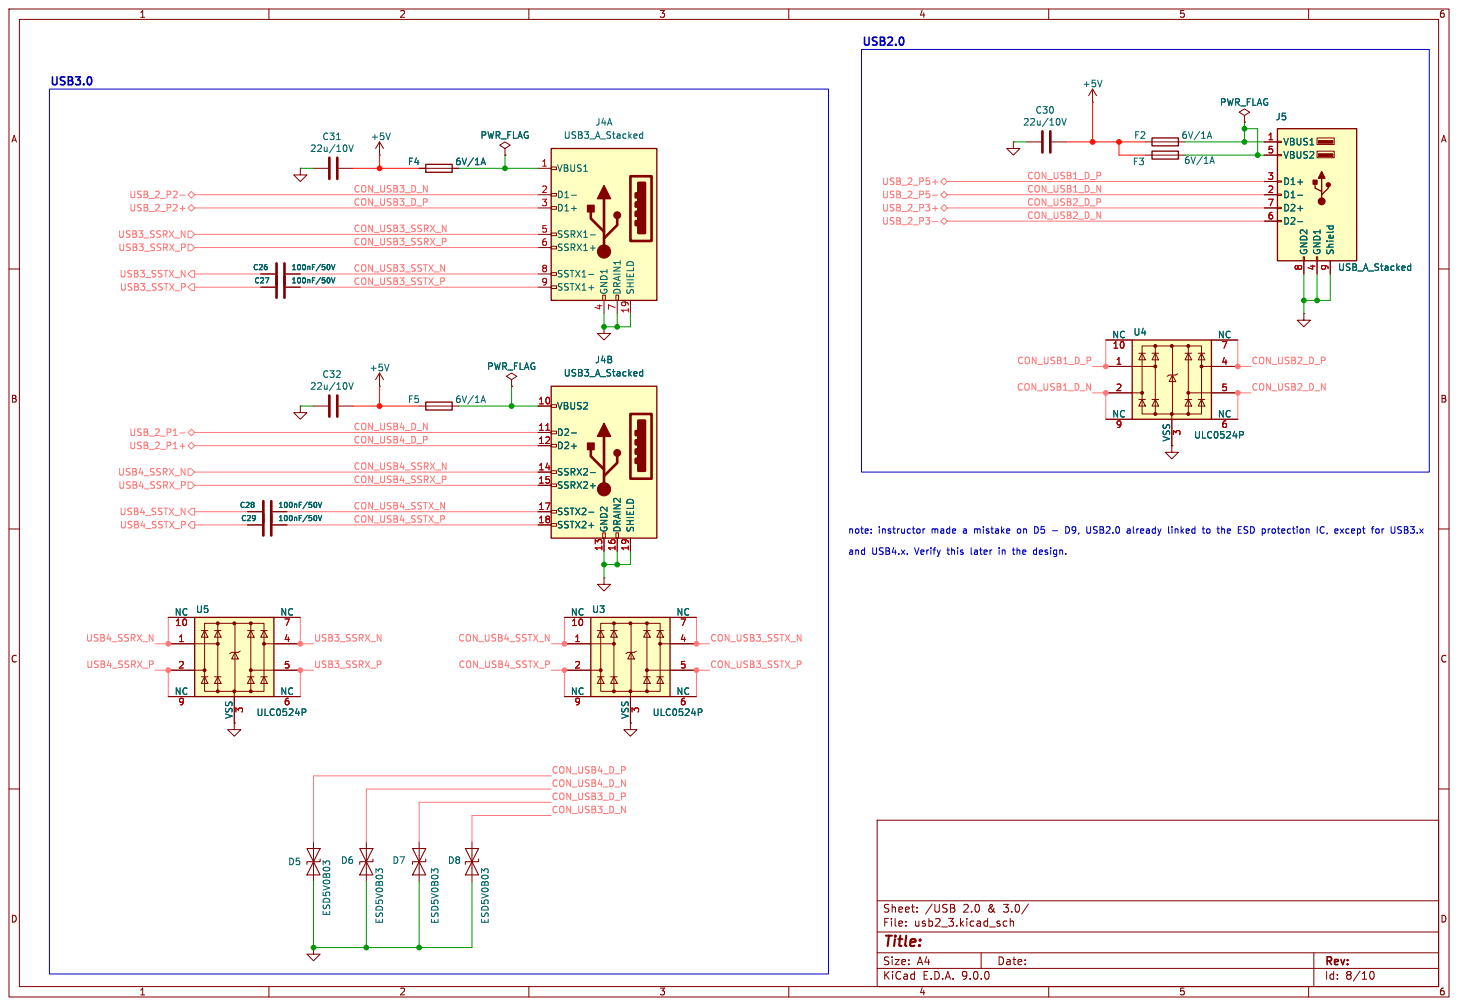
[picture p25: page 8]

and USB4.x. Verify this later in the design.

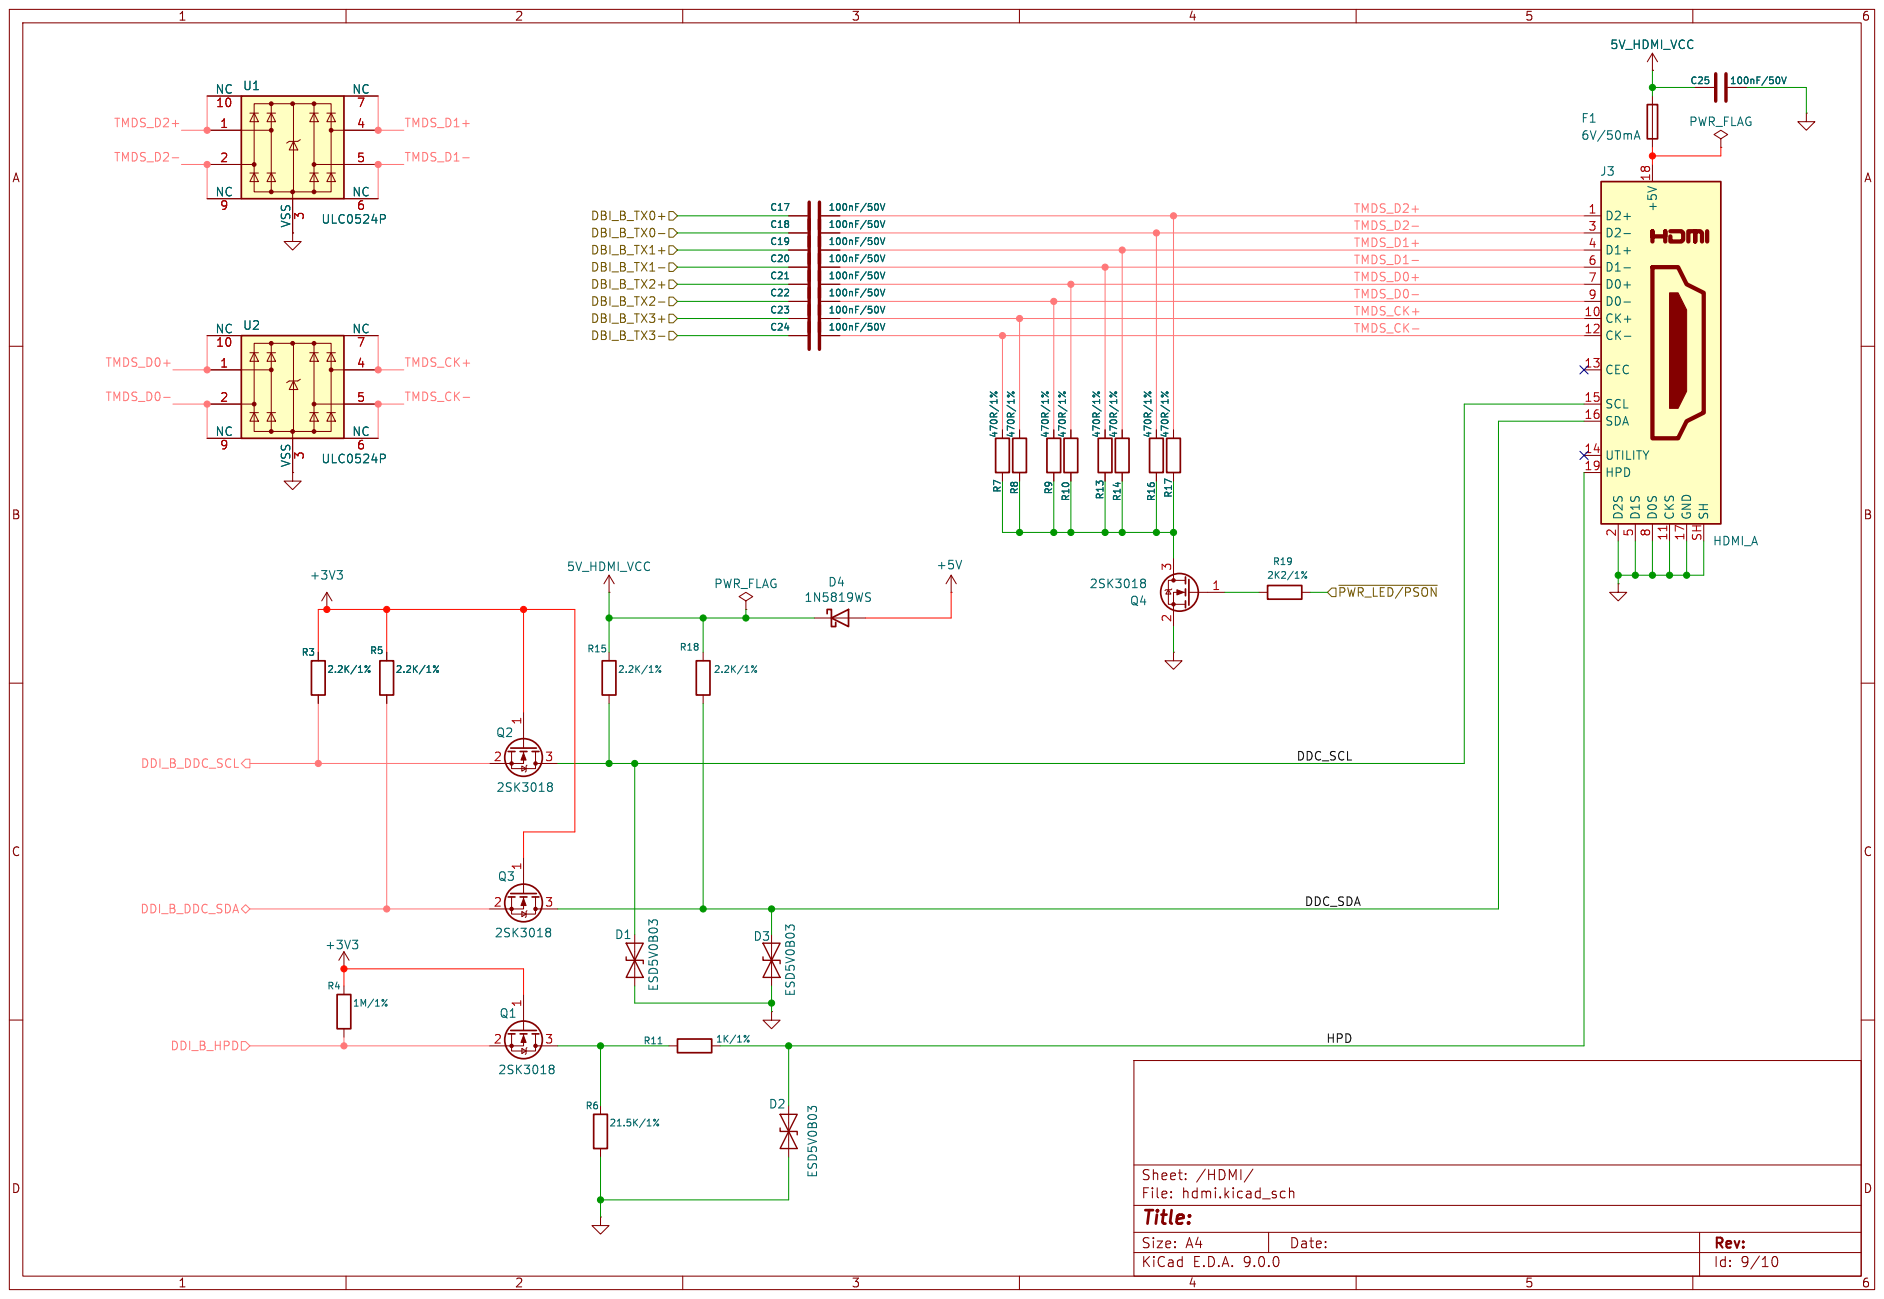
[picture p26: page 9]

Id: 9/10 Title: File: hdmi.kicad_sch Sheet: /HDMI/ R14 470R/1%

8 CKS 11 GND 17 SH SH

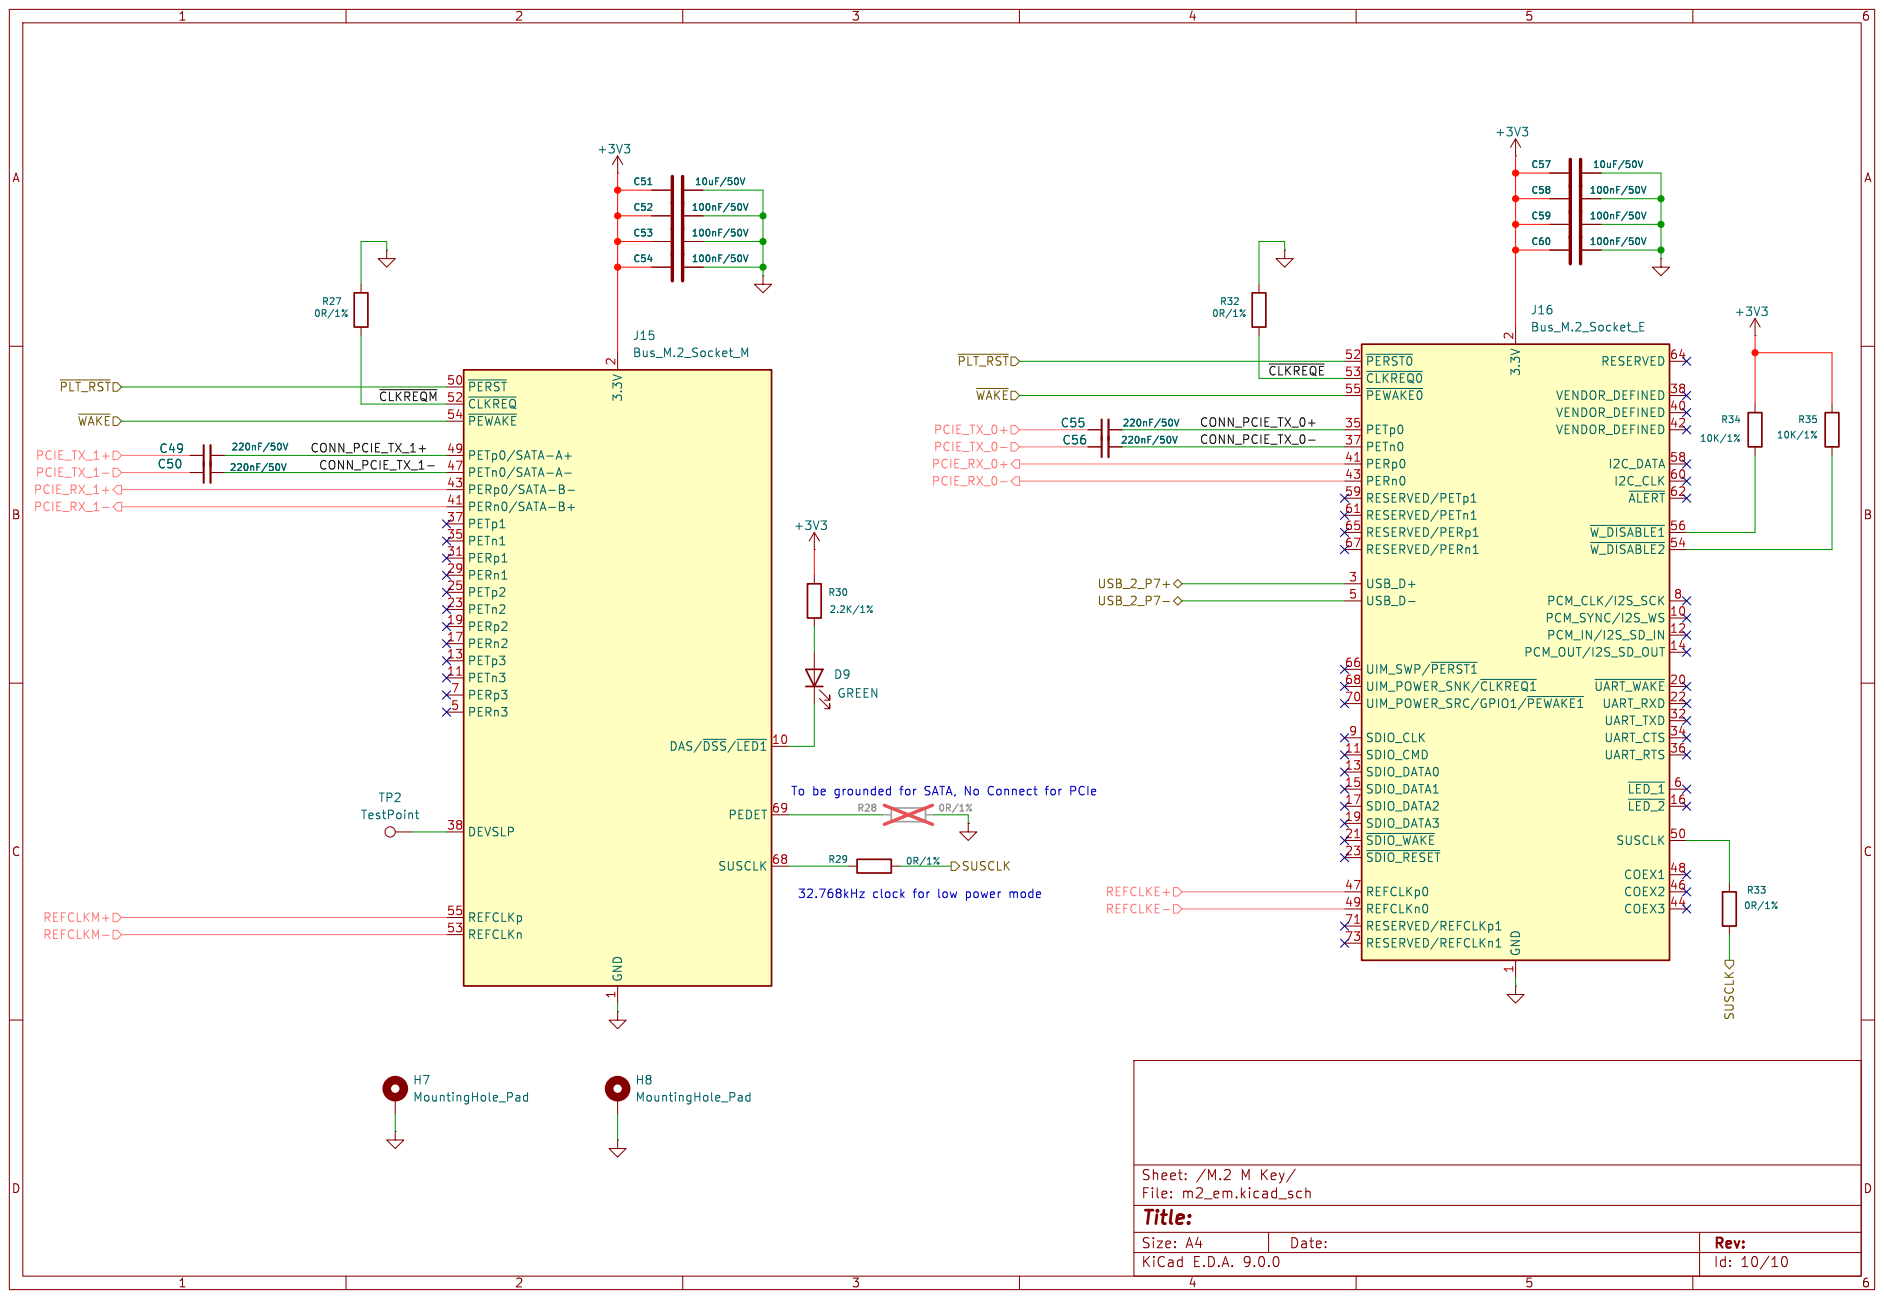
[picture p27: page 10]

1 DAS/~{DSS}/~{LED1} 10 PEDET 69 SUSCLK 68

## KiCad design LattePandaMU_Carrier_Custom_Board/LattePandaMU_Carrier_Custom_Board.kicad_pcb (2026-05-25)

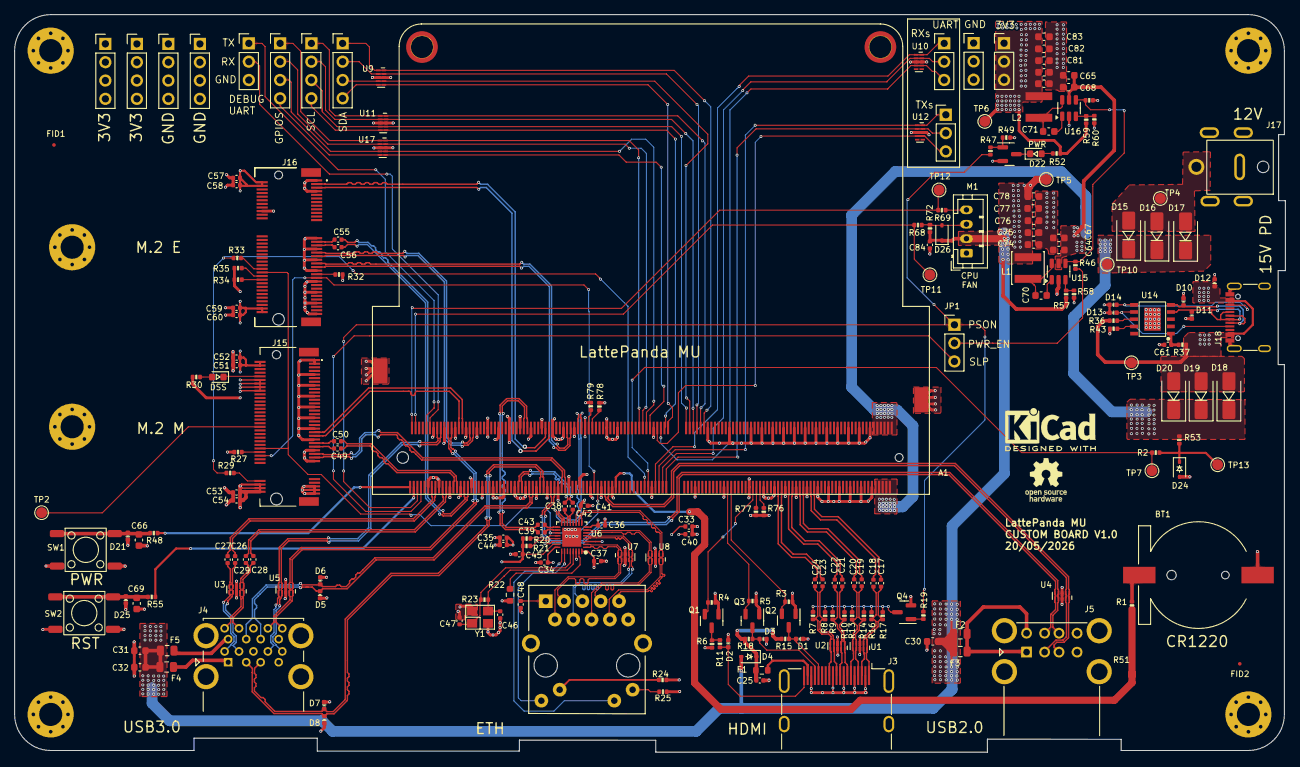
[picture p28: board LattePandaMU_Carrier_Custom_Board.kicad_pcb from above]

Board: 4 copper layers, 176.1 x 102.2 mm, 218 parts (1 on the bottom side), 171 nets.

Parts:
A1: LattePanda_Mu; LattePanda_Module_H8.0mm_Horizontal
BT1: Battery_Cell; Battery_Holder_CR1220_S8411-45R
C17, C18, C19, C20, C21, C22, C23, C24, C25, C26, C27, C28, C29, C52, C53, C54, C58, C59, C60: 100nF/50V; C_0402_1005Metric
C30, C31, C32, C64, C65, C67, C68, C74, C75, C77, C78, C79, C80, C82, C83: 22u/10V; C_0603_1608Metric
C33, C34, C35, C36, C37, C38, C39, C40, C41, C42, C43, C45, C48, C84: 100n/50V; C_0402_1005Metric
C44: 10u/50V; C_0402_1005Metric
C46, C47: 12p/50V; C_0402_1005Metric
C49, C50, C55, C56: 220nF/50V; C_0402_1005Metric
C51, C57: 10uF/50V; C_0402_1005Metric
C61: 1u/16V; C_0402_1005Metric
C66, C69: 1u/16V; C_0603_1608Metric
C70, C71: 100n/50V; C_0603_1608Metric
C76, C81: 100n/10V; C_0603_1608Metric
D1, D2, D3, D5, D6, D7, D8: ESD5V0B03; D_0402_1005Metric
D4: 1N5819WS; D_SOD-323
D9: GREEN; LED_0603_1608Metric
D10, D11, D21, D25: ESD9B5.0ST5G; D_0402_1005Metric
D12, D13, D14: D_Zener; D_0402_1005Metric
D15, D16, D17, D18, D19, D20: D_Schottky; D_SMA
D22: LED; LED_0603_1608Metric
D24: 3V3 Izt=5mA; D_SOD-323
D26: 1N5819; D_SOD-323
F1: 6V/50mA; R_0603_1608Metric
F2, F3, F4, F5: 6V/1A; Fuse_0805_2012Metric
FID1, FID2: Fiducial; Fiducial_0.5mm_Mask1mm
H1, H2, H3, H4, H7, H8: MountingHole_Pad; MountingHole_3.2mm_M3_Pad_Via
H5, H6: MountingHole_Pad; MountingHole_3mm_M2_Pad_TopOnly
J1, J8, J10, J11, J14: Conn_01x03_Pin; PinHeader_1x03_P2.54mm_Vertical
J3: HDMI_A; HDMI_A_Molex_208658-1001_Horizontal
J4: USB3_A_Stacked; USB3_A_Molex_48406-0001_Horizontal_Stacked
J5: USB_A_Stacked; USB_A_CUI_UJ2-ADH-TH_Horizontal_Stacked
J6: RJ45_RB1-125B8G1A; RJ45_UDE_RB1-125B8G1A
J7, J9, J12, J13, J19, J20, J21: Conn_01x04_Pin; PinHeader_1x04_P2.54mm_Vertical
J15: Bus_M.2_Socket_M; PCIe_M.2_Connectors_P=0.5mm_H=4.2mm_KeyM
J16: Bus_M.2_Socket_E; PCIe_M.2_Connectors_P=0.5mm_H=4.2mm_KeyE
J17: Barrel_Jack_Switch; DC_Jack_DC007B_30V_10A
J18: USB_C_Receptacle_USB2.0_16P; USB_C_Receptacle_G-Switch_GT-USB-7010ASV
JP1: Jumper_3_Bridged12; PinHeader_1x03_P2.54mm_Vertical
L1, L2: 2u2/4.3A; L_Sunlord_SWPA4020S
M1: Fan_4pin; JST_PH_B4B-PH-K_1x04_P2.00mm_Vertical
Q1, Q2, Q3, Q4: 2SK3018; SOT-23
Q8: 2N7002; SOT-23
R1, R11, R37, R47: 1K/1%; R_0402_1005Metric
R2, R20, R21, R34, R35, R36, R49, R58, R78, R79: 10K/1%; R_0402_1005Metric
R3, R5, R15, R18, R30: 2.2K/1%; R_0402_1005Metric
R4, R23: 1M/1%; R_0402_1005Metric
R6: 21.5K/1%; R_0402_1005Metric
R7, R8, R9, R10, R13, R14, R16, R17, R24, R25: 470R/1%; R_0402_1005Metric
R19, R52, R53: 2K2/1%; R_0402_1005Metric
R22: 2K49/1%; R_0603_1608Metric
R27, R29, R32, R33: 0R/1%; R_0402_1005Metric
R43: 56K/1%; R_0402_1005Metric
R46, R48, R55, R69: 100R/1%; R_0402_1005Metric
R51, R76, R77: 100K/1%; R_0402_1005Metric
R57: 75K/1%; R_0402_1005Metric
R59: 21K5K/1%; R_0402_1005Metric
R60, R72: 4K7/1%; R_0402_1005Metric
R68: 21K5/1%; R_0402_1005Metric
SW1, SW2: SW_Push; SW_Push_6x6x6
TP2, TP3, TP4, TP5, TP6, TP7, TP10, TP11, TP12, TP13: TestPoint; TestPoint_Pad_D1.5mm
U1, U2, U3, U4, U5, U7, U8, U9, U10, U11, U12, U17: ULC0524P; Diodes_UDFN-10_1.0x2.5mm_P0.5mm
U6: RTL8111H-CG-RH; QFN-32-1EP_4x4mm_P0.4mm_EP2.65x2.65mm
U14: USB PD等快充协议受电芯片-CH224K-ESSOP10; ESSOP-10-1EP_3.9x5mm_P1.0mm_EP3.2x2.3
U15, U16: LM2734X; TSOT-23-6
Xigote_Log: LOGO; Footprint_logos
Y1: 25MHz; Crystal_SMD_3225-4Pin_3.2x2.5mm

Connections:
5V_HDMI_VCC: C25.1, D4.1 (K), F1.1, R15.1, R18.1
+1V0: C33.1, C34.1, C35.1, C36.1, C40.1, C44.1, U6.3 (AVDD10), U6.8 (AVDD10), U6.22 (DVDD10), U6.24 (REGOUT), U6.30 (AVDD10)
+3V3: C37.1, C41.1, C45.1, C51.1, C52.1, C53.1, C54.1, C57.1, C58.1, C59.1, C60.1, C79.2, C80.2, C81.2, C82.2, C83.2, J13.1, J13.2, J13.3, J13.4, J14.1, J14.2, J14.3, J15.2 (3.3V), J15.4 (3.3V), J15.12 (3.3V), J15.14 (3.3V), J15.16 (3.3V), J15.18 (3.3V), J15.70 (3.3V), J15.72 (3.3V), J15.74 (3.3V), J16.2 (3.3V), J16.4 (3.3V), J16.72 (3.3V), J16.74 (3.3V), J21.1, J21.2, J21.3, J21.4, L2.2, Q1.1 (G), Q2.1 (G), Q3.1 (G), R3.1, R4.1, R5.1, R20.2, R21.2, R24.2, R25.2, R30.2, R34.2, R35.2, R52.2, R59.2, TP6.1, U6.11 (AVDD33), U6.23 (VDDREG), U6.32 (AVDD33)
+5V: C30.2, C31.2, C32.2, C74.2, C75.2, C76.2, C77.2, C78.2, C84.1, D4.2 (A), D26.1 (K), F2.1, F3.1, F4.1, F5.1, L1.2, M1.2 (+), R57.2, R72.2, TP5.1
+12V: D15.2 (A), D16.2 (A), D17.2 (A), J17.1, TP4.1
+15V: D12.1 (K), D18.2 (A), D19.2 (A), D20.2 (A), J18.A4 (VBUS), J18.A9 (VBUS), J18.B4 (VBUS), J18.B9 (VBUS), R36.1, R37.1, TP3.1
+BATT: A1.115 (VBAT), R1.2
/Fan/FAN_1_PWM: A1.2 (FAN1_PWM), R69.2, TP12.1
/Fan/FAN_1_TAC: A1.4 (FAN1_TAC), R68.2, TP11.1
/GPIO/GPP_D0: A1.128 (GPP_D0), J19.1, U17.1, U17.10 (NC)
/GPIO/GPP_D1: A1.130 (GPP_D1), J19.2, U17.2, U17.9 (NC)
/GPIO/GPP_D2: A1.132 (GPP_D2), J19.3, U17.4, U17.7 (NC)
/GPIO/GPP_D3: A1.134 (GPP_D3), J19.4, U17.5, U17.6 (NC)
/GPIO/I2C2_SCL: A1.154 (I2C2_SCL), J9.1, U11.1, U11.10 (NC)
/GPIO/I2C2_SDA: A1.156 (I2C2_SDA), J7.1, U9.1, U9.10 (NC)
/GPIO/I2C3_SCL: A1.150 (I2C3_SCL), J9.2, U11.2, U11.9 (NC)
/GPIO/I2C3_SDA: A1.152 (I2C3_SDA), J7.2, U9.2, U9.9 (NC)
/GPIO/I2C4_SCL: A1.146 (I2C4_SCL), J9.3, U11.4, U11.7 (NC)
/GPIO/I2C4_SDA: A1.148 (I2C4_SDA), J7.3, U9.4, U9.7 (NC)
/GPIO/I2C5_SCL: A1.142 (I2C5_SCL), J9.4, U11.5, U11.6 (NC)
/GPIO/I2C5_SDA: A1.144 (I2C5_SDA), J7.4, U9.5, U9.6 (NC)
/GPIO/SOC_UART0_RX: A1.137 (UART0_RXD), J8.1, U10.1, U10.10 (NC)
/GPIO/SOC_UART0_TX: A1.139 (UART0_TXD), J10.1, U12.1, U12.10 (NC)
/GPIO/SOC_UART1_RX: A1.141 (UART1_RXD), J8.2, U10.2, U10.9 (NC)
/GPIO/SOC_UART1_TX: A1.143 (UART1_TXD), J10.2, U12.2, U12.9 (NC)
/GPIO/SOC_UART2_RX: A1.140 (UART2_RXD), J8.3, U10.4, U10.7 (NC)
/GPIO/SOC_UART2_TX: A1.138 (UART2_TXD), J10.3, U12.4, U12.7 (NC)
/Gigabit Ethernet/GbE_PCIe_CLK+: A1.94 (REFCLK4+), U6.15 (REFCLK_P)
/Gigabit Ethernet/GbE_PCIe_CLK-: A1.96 (REFCLK4-), U6.16 (REFCLK_N)
/Gigabit Ethernet/GbE_PCIe_RX+: A1.64 (HSIO6_RX+), C43.1
/Gigabit Ethernet/GbE_PCIe_RX-: A1.66 (HSIO6_RX-), C39.1
/Gigabit Ethernet/GbE_PCIe_TX+: A1.61 (HSIO6_TX+), C42.1
/Gigabit Ethernet/GbE_PCIe_TX-: A1.63 (HSIO6_TX-), C38.1
/Gigabit Ethernet/HSI+: C42.2, U6.13 (HSIP)
/Gigabit Ethernet/HSI-: C38.2, U6.14 (HSIN)
/Gigabit Ethernet/HSO+: C43.2, U6.17 (HSOP)
/Gigabit Ethernet/HSO-: C39.2, U6.18 (HSON)
/Gigabit Ethernet/MDI0+: J6.R2 (TD1+), U6.1 (MDIP0), U7.1, U7.10 (NC)
/Gigabit Ethernet/MDI0-: J6.R3 (TD1-), U6.2 (MDIN0), U7.2, U7.9 (NC)
/Gigabit Ethernet/MDI1+: J6.R4 (TD2+), U6.4 (MDIP1), U7.4, U7.7 (NC)
/Gigabit Ethernet/MDI1-: J6.R5 (TD2-), U6.5 (MDIN1), U7.5, U7.6 (NC)
/Gigabit Ethernet/MDI2+: J6.R6 (TD3+), U6.6 (MDIP2), U8.5, U8.6 (NC)
/Gigabit Ethernet/MDI2-: J6.R7 (TD3-), U6.7 (MDIN2), U8.4, U8.7 (NC)
/Gigabit Ethernet/MDI3+: J6.R8 (TD4+), U6.9 (MDIP3), U8.2, U8.9 (NC)
/Gigabit Ethernet/MDI3-: J6.R9 (TD4-), U6.10 (MDIN3), U8.1, U8.10 (NC)
/HDMI/DBI_B_TX0+: A1.217 (DDIB_TX0+), C17.1
/HDMI/DBI_B_TX0-: A1.215 (DDIB_TX0-), C18.1
/HDMI/DBI_B_TX1+: A1.211 (DDIB_TX1+), C19.1
/HDMI/DBI_B_TX1-: A1.209 (DDIB_TX1-), C20.1
/HDMI/DBI_B_TX2+: A1.205 (DDIB_TX2+), C21.1
/HDMI/DBI_B_TX2-: A1.203 (DDIB_TX2-), C22.1
/HDMI/DBI_B_TX3+: A1.199 (DDIB_TX3+), C23.1
/HDMI/DBI_B_TX3-: A1.197 (DDIB_TX3-), C24.1
/HDMI/DDC_SCL: D1.2 (A2), J3.15 (SCL), Q2.3 (D), R15.2
/HDMI/DDC_SDA: D3.2 (A2), J3.16 (SDA), Q3.3 (D), R18.2
/HDMI/DDI_B_DDC_SCL: A1.171 (DDIB_DDC_SCL), Q2.2 (S), R3.2
/HDMI/DDI_B_DDC_SDA: A1.169 (DDIB_DDC_SDA), Q3.2 (S), R5.2
/HDMI/DDI_B_HPD: A1.183 (DDIB_HPD), Q1.2 (S), R4.2
/HDMI/HPD: D2.2 (A2), J3.19 (HPD), R11.2
/HDMI/TMDS_CK+: C23.2, J3.10 (CK+), R8.1, U2.4, U2.7 (NC)
/HDMI/TMDS_CK-: C24.2, J3.12 (CK-), R7.1, U2.5, U2.6 (NC)
/HDMI/TMDS_D0+: C21.2, J3.7 (D0+), R10.1, U2.1, U2.10 (NC)
/HDMI/TMDS_D0-: C22.2, J3.9 (D0-), R9.1, U2.2, U2.9 (NC)
/HDMI/TMDS_D1+: C19.2, J3.4 (D1+), R14.1, U1.4, U1.7 (NC)
/HDMI/TMDS_D1-: C20.2, J3.6 (D1-), R13.1, U1.5, U1.6 (NC)
/HDMI/TMDS_D2+: C17.2, J3.1 (D2+), R17.1, U1.1, U1.10 (NC)
/HDMI/TMDS_D2-: C18.2, J3.3 (D2-), R16.1, U1.2, U1.9 (NC)
/LattePanda Module/HSIO_0_TX+: A1.13 (HSIO0_TX+), C27.1
/LattePanda Module/HSIO_0_TX-: A1.15 (HSIO0_TX-), C26.1
/LattePanda Module/HSIO_1_TX+: A1.19 (HSIO1_TX+), C29.1
/LattePanda Module/HSIO_1_TX-: A1.21 (HSIO1_TX-), C28.1
/LattePanda Module/HSIO_2_RX+: A1.28 (HSIO2_RX+), J15.43 (PERp0/SATA-B-)
/LattePanda Module/HSIO_2_RX-: A1.30 (HSIO2_RX-), J15.41 (PERn0/SATA-B+)
/LattePanda Module/HSIO_2_TX+: A1.25 (HSIO2_TX+), C49.1
/LattePanda Module/HSIO_2_TX-: A1.27 (HSIO2_TX-), C50.1
/LattePanda Module/HSIO_3_RX+: A1.34 (HSIO3_RX+), J16.41 (PERp0)
/LattePanda Module/HSIO_3_RX-: A1.36 (HSIO3_RX-), J16.43 (PERn0)
/LattePanda Module/HSIO_3_TX+: A1.31 (HSIO3_TX+), C55.1
/LattePanda Module/HSIO_3_TX-: A1.33 (HSIO3_TX-), C56.1
/LattePanda Module/REFCLK0+: A1.85 (REFCLK0+), J15.55 (REFCLKp)
/LattePanda Module/REFCLK0-: A1.87 (REFCLK0-), J15.53 (REFCLKn)
/LattePanda Module/REFCLK3+: A1.88 (REFCLK3+), J16.47 (REFCLKp0)
/LattePanda Module/REFCLK3-: A1.90 (REFCLK3-), J16.49 (REFCLKn0)
/LattePanda Module/SLS_S3: A1.7 (SLS_S3), JP1.3 (B)
/LattePanda Module/SUSCLK_WIFI: A1.131 (SUSCLK), R29.2, R33.1
/LattePanda Module/USB2_P7+: A1.76 (USB2_P7+), J16.3 (USB_D+)
/LattePanda Module/USB2_P7-: A1.78 (USB2_P7-), J16.5 (USB_D-)
/LattePanda Module/~PWR_SW: A1.1 (~PWRBTN), R48.1
/LattePanda Module/~RST_SW: A1.3 (~RSTBTN), R55.1
/M.2 M Key/CONN_PCIE_TX_0+: C55.2, J16.35 (PETp0)
/M.2 M Key/CONN_PCIE_TX_0-: C56.2, J16.37 (PETn0)
/M.2 M Key/CONN_PCIE_TX_1+: C49.2, J15.49 (PETp0/SATA-A+)
/M.2 M Key/CONN_PCIE_TX_1-: C50.2, J15.47 (PETn0/SATA-A-)
/M.2 M Key/~CLKREQE: J16.53 (~CLKREQ0), R32.1
/M.2 M Key/~CLKREQM: J15.52 (~CLKREQ), R27.1
/Power Supply/CC1: D13.1 (K), J18.A5 (CC1), U14.7 (CC1)
/Power Supply/CC2: D14.1 (K), J18.B5 (CC2), U14.6 (CC2)
/Power Supply/PWR_C_D+: D11.2 (A2), J18.A6 (D+), J18.B6 (D+), U14.4 (DP)
/Power Supply/PWR_C_D-: D10.2 (A2), J18.A7 (D-), J18.B7 (D-), U14.5 (DM)
/Power Supply/PWR_EN: R46.2, R51.2, U15.4 (EN), U16.4 (EN)
/USB 2.0 & 3.0/CON_USB1_D_N: A1.109 (USB2_P5-), J5.2 (D1-), U4.2, U4.9 (NC)
/USB 2.0 & 3.0/CON_USB1_D_P: A1.111 (USB2_P5+), J5.3 (D1+), U4.1, U4.10 (NC)
/USB 2.0 & 3.0/CON_USB2_D_N: A1.79 (USB2_P3-), J5.6 (D2-), U4.5, U4.6 (NC)
/USB 2.0 & 3.0/CON_USB2_D_P: A1.81 (USB2_P3+), J5.7 (D2+), U4.4, U4.7 (NC)
/USB 2.0 & 3.0/CON_USB3_D_N: A1.73 (USB2_P2-), D8.2 (A2), J4.2 (D1-)
/USB 2.0 & 3.0/CON_USB3_D_P: A1.75 (USB2_P2+), D7.2 (A2), J4.3 (D1+)
/USB 2.0 & 3.0/CON_USB3_SSRX_N: A1.18 (HSIO0_RX-), J4.5 (SSRX1-), U5.4, U5.7 (NC)
/USB 2.0 & 3.0/CON_USB3_SSRX_P: A1.16 (HSIO0_RX+), J4.6 (SSRX1+), U5.5, U5.6 (NC)
/USB 2.0 & 3.0/CON_USB3_SSTX_N: C26.2, J4.8 (SSTX1-), U3.4, U3.7 (NC)
/USB 2.0 & 3.0/CON_USB3_SSTX_P: C27.2, J4.9 (SSTX1+), U3.5, U3.6 (NC)
/USB 2.0 & 3.0/CON_USB4_D_N: A1.67 (USB2_P1-), D6.2 (A2), J4.11 (D2-)
/USB 2.0 & 3.0/CON_USB4_D_P: A1.69 (USB2_P1+), D5.2 (A2), J4.12 (D2+)
/USB 2.0 & 3.0/CON_USB4_SSRX_N: A1.24 (HSIO1_RX-), J4.14 (SSRX2-), U5.1, U5.10 (NC)
/USB 2.0 & 3.0/CON_USB4_SSRX_P: A1.22 (HSIO1_RX+), J4.15 (SSRX2+), U5.2, U5.9 (NC)
/USB 2.0 & 3.0/CON_USB4_SSTX_N: C28.2, J4.17 (SSTX2-), U3.1, U3.10 (NC)
/USB 2.0 & 3.0/CON_USB4_SSTX_P: C29.2, J4.18 (SSTX2+), U3.2, U3.9 (NC)
/~PLT_RST: A1.105 (~PLTRST), J15.50 (~PERST), J16.52 (~PERST0), U6.19 (PERSTB)
/~PWR_LED/PSON: A1.5 (SLS_S0), JP1.1 (A), R19.2, R47.1
/~WAKE: A1.103 (~WAKE), J15.54 (~PEWAKE), J16.55 (~PEWAKE0)
GND: A1.11 (GND), A1.14 (GND), A1.17 (GND), A1.20 (GND), A1.23 (GND), A1.26 (GND), A1.29 (GND), A1.32 (GND), A1.35 (GND), A1.38 (GND), A1.41 (GND), A1.44 (GND), A1.47 (GND), A1.50 (GND), A1.53 (GND), A1.56 (GND), A1.59 (GND), A1.62 (GND), A1.65 (GND), A1.68 (GND), A1.71 (GND), A1.74 (GND), A1.77 (GND), A1.80 (GND), A1.83 (GND), A1.86 (GND), A1.89 (GND), A1.92 (GND), A1.95 (GND), A1.98 (GND), A1.101 (GND), A1.107 (GND), A1.110 (GND), A1.113 (GND), A1.116 (GND), A1.135 (GND), A1.136 (GND), A1.151 (GND), A1.158 (GND), A1.167 (GND), A1.170 (GND), A1.181 (GND), A1.182 (GND), A1.188 (GND), A1.189 (GND), A1.194 (GND), A1.195 (GND), A1.200 (GND), A1.201 (GND), A1.206 (GND), A1.207 (GND), A1.212 (GND), A1.213 (GND), A1.218 (GND), A1.219 (GND), A1.224 (GND), A1.225 (GND), A1.230 (GND), A1.231 (GND), A1.236 (GND), A1.237 (GND), A1.242 (GND), A1.243 (GND), A1.248 (GND), A1.249 (GND), A1.MP (Mountinge_Pads), BT1.2 (-), C25.2, C30.1, C31.1, C32.1, C33.2, C34.2, C35.2, C36.2, C37.2, C40.2, C41.2, C44.2, C45.2, C46.1, C47.1, C48.1, C51.2, C52.2, C53.2, C54.2, C57.2, C58.2, C59.2, C60.2, C61.1, C64.1, C65.2, C66.1, C67.1, C68.2, C69.1, C74.1, C75.1, C76.1, C77.1, C78.1, C79.1, C80.1, C81.1, C82.1, C83.1, C84.2, D1.1 (A1), D2.1 (A1), D3.1 (A1), D5.1 (A1), D6.1 (A1), D7.1 (A1), D8.1 (A1), D10.1 (A1), D11.1 (A1), D12.2 (A), D13.2 (A), D14.2 (A), D21.1 (A1), D24.2 (A), D25.1 (A1), H1.1, H2.1, H3.1, H4.1, H5.1, H6.1, H7.1, H8.1, J1.3, J3.2 (D2S), J3.5 (D1S), J3.8 (D0S), J3.11 (CKS), J3.17 (GND), J3.SH, J4.4 (GND1), J4.7 (DRAIN1), J4.13 (GND2), J4.16 (DRAIN2), J4.19 (SHIELD), J5.4 (GND1), J5.8 (GND2), J5.9 (Shield), J6.R10 (GND), J6.SH, J11.1, J11.2, J11.3, J12.1, J12.2, J12.3, J12.4, J15.1 (GND), J15.3 (GND), J15.9 (GND), J15.15 (GND), J15.21 (GND), J15.27 (GND), J15.33 (GND), J15.39 (GND), J15.45 (GND), J15.51 (GND), J15.57 (GND), J15.71 (GND), J15.73 (GND), J15.75 (GND), J16.1 (GND), J16.7 (GND), J16.18 (GND), J16.33 (GND), J16.39 (GND), J16.45 (GND), J16.51 (GND), J16.57 (GND), J16.63 (GND), J16.69 (GND), J16.75 (GND), J17.2, J17.3, J18.A1 (GND), J18.A12 (GND), J18.B1 (GND), J18.B12 (GND), J18.S1 (SHIELD), J20.1, J20.2, J20.3, J20.4, M1.1 (-), Q4.2 (S), Q8.2 (S), R6.2, R22.1, R27.2, R32.2, R43.2, R49.1, R51.1, R58.1, R60.1, R76.1, R77.1, R78.1, R79.1, SW1.2, SW2.2, U1.3 (VSS), U1.8 (VSS), U2.3 (VSS), U2.8 (VSS), U3.3 (VSS), U3.8 (VSS), U4.3 (VSS), U4.8 (VSS), U5.3 (VSS), U5.8 (VSS), U6.33 (GND), U7.3 (VSS), U7.8 (VSS), U8.3 (VSS), U8.8 (VSS), U9.3 (VSS), U9.8 (VSS), U10.3 (VSS), U10.8 (VSS), U11.3 (VSS), U11.8 (VSS), U12.3 (VSS), U12.8 (VSS), U14.0 (GND), U15.2 (GND), U16.2 (GND), U17.3 (VSS), U17.8 (VSS), Y1.2, Y1.4
unnamed: A1.12 (SIO_UART_RX), J1.2
unnamed: A1.10 (SIO_UART_TX), J1.1
unnamed: A1.187 (TCP0_HPD), R76.2
unnamed: A1.185 (TCP1_HPD), R77.2
unnamed: A1.133 (~BIOS_SEL), R2.1, TP7.1
unnamed: A1.100 (~CLKREQ3), R79.2
unnamed: A1.102 (~CLKREQ4), R78.2
unnamed: BT1.1 (+), R1.1
unnamed: D9.2 (A), R30.1
unnamed: D9.1 (K), J15.10 (DAS/~DSS/~LED1)
unnamed: C66.2, D21.2 (A2), R48.2, SW1.1
unnamed: D22.2 (A), R52.1
unnamed: D22.1 (K), Q8.3 (D)
unnamed: C69.2, D25.2 (A2), R55.2, SW2.1
unnamed: D26.2 (A), M1.3 (Tacho), R68.1, R72.1
unnamed: F1.2, J3.18 (+5V)
unnamed: F4.2, J4.1 (VBUS1)
unnamed: F5.2, J4.10 (VBUS2)
unnamed: F2.2, F3.2, J5.1 (VBUS1), J5.5 (VBUS2)
unnamed: C48.2, J6.R1 (CT)
unnamed: J6.L1, R25.1
unnamed: J6.L3, R24.1
unnamed: J15.38 (DEVSLP), TP2.1
unnamed: J15.68 (SUSCLK), R29.1
unnamed: J16.50 (SUSCLK), R33.2
unnamed: J16.56 (~W_DISABLE1), R34.1
unnamed: J16.54 (~W_DISABLE2), R35.1
unnamed: JP1.2 (C), R46.1
unnamed: M1.4 (PWM), R69.1
unnamed: Q1.3 (D), R6.1, R11.1
unnamed: Q4.3 (D), R7.2, R8.2, R9.2, R10.2, R13.2, R14.2, R16.2, R17.2
unnamed: Q4.1 (G), R19.1
unnamed: Q8.1 (G), R47.2, R49.2
unnamed: C47.2, R23.1, U6.28 (CKXTAL1), Y1.1
unnamed: C46.2, R23.2, U6.29 (CKXTAL2), Y1.3
unnamed: R20.1, U6.20 (ISOLATEB)
unnamed: R21.1, U6.21 (LANWAKEB)
unnamed: J6.L4, U6.26 (LED1)
unnamed: J6.L2, U6.25 (LED2)
unnamed: R22.2, U6.31 (RSET)
unnamed: R43.1, U14.9 (CFG1)
unnamed: R36.2, U14.8 (VBUS)
unnamed: C61.2, R37.2, U14.1 (VDD)
unnamed: C70.1, U15.1 (BOOST)
unnamed: R57.1, R58.2, U15.3 (FB)
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

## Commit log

2026-05-25 Adding PCB Layout
    [PCB_3D_Model_TOP.step]
2026-05-25 ADDING HDMI and ETH routing
    [LattePandaMU_Carrier_Custom_Board.kicad_pcb]
2026-05-25 adding PCB STACKUP AND IMPEDANCE CALCULATOR
